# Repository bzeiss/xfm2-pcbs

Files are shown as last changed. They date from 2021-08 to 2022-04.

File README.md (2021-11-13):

# PCB(s) for the XFM2/XVA1 Project

This site contains some stuff I have built for the excellent FPGA XFM2/XVA FPGA DIY synths by futur3soundz/René Ceballos. You can find them here: https://www.futur3soundz.com.

I tinker with electronics, release stuff when I feel like it and I make it public when it's maybe not perfect. I'm not an electronics expert, so I may not always know what I'm doing. I learn the necessary electronics as I use it. Use at your own risk.

Feedback is always very welcome 😄 Feel free to ask question in the [discussions](https://github.com/bzeiss/xfm2-pcbs/discussions).

***

The main content of this site (descriptions, documentations) can be found **[in the Wiki](https://github.com/bzeiss/xfm2-pcbs/wiki)**.

Entrance (https://github.com/bzeiss/xfm2-pcbs/wiki)

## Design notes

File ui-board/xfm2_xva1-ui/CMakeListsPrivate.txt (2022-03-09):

# !!! WARNING !!! AUTO-GENERATED FILE, PLEASE DO NOT MODIFY IT AND USE
# https://docs.platformio.org/page/projectconf/section_env_build.html#build-flags
#
# If you need to override existing CMake configuration or add extra,
# please create `CMakeListsUser.txt` in the root of project.
# The `CMakeListsUser.txt` will not be overwritten by PlatformIO.

set(CMAKE_CONFIGURATION_TYPES "megaatmega2560" CACHE STRING "Build Types reflect PlatformIO Environments" FORCE)

# Convert "Home Directory" that may contain unescaped backslashes on Windows
file(TO_CMAKE_PATH $ENV{HOMEDRIVE}$ENV{HOMEPATH} ENV_HOME_PATH)

SET(CMAKE_C_COMPILER "${ENV_HOME_PATH}/.platformio/packages/toolchain-atmelavr/bin/avr-gcc.exe")
SET(CMAKE_CXX_COMPILER "${ENV_HOME_PATH}/.platformio/packages/toolchain-atmelavr/bin/avr-g++.exe")
SET(CMAKE_CXX_FLAGS "-fno-exceptions -fno-threadsafe-statics -fpermissive -std=gnu++11 -Wno-unknown-pragmas -Os -Wall -ffunction-sections -fdata-sections -flto -mmcu=atmega2560")
SET(CMAKE_C_FLAGS "-std=gnu11 -fno-fat-lto-objects -Wno-unknown-pragmas -Os -Wall -ffunction-sections -fdata-sections -flto -mmcu=atmega2560")

SET(CMAKE_C_STANDARD 11)
set(CMAKE_CXX_STANDARD 11)

if (CMAKE_BUILD_TYPE MATCHES "megaatmega2560")
    add_definitions(-DPLATFORMIO=50205)
    add_definitions(-DARDUINO_AVR_MEGA2560)
    add_definitions(-DF_CPU=16000000L)
    add_definitions(-DARDUINO_ARCH_AVR)
    add_definitions(-DARDUINO=10808)
    add_definitions(-D__AVR_ATmega2560__)

    include_directories("${CMAKE_CURRENT_LIST_DIR}/include")
    include_directories("${CMAKE_CURRENT_LIST_DIR}/src")
    include_directories("${CMAKE_CURRENT_LIST_DIR}/.pio/libdeps/megaatmega2560/Adafruit MCP23017 Arduino Library/src")
    include_directories("${CMAKE_CURRENT_LIST_DIR}/.pio/libdeps/megaatmega2560/Adafruit BusIO")
    include_directories("${CMAKE_CURRENT_LIST_DIR}/.pio/libdeps/megaatmega2560/SoftwareSerial")
    include_directories("${CMAKE_CURRENT_LIST_DIR}/.pio/libdeps/megaatmega2560/U8g2/src")
    include_directories("${ENV_HOME_PATH}/.platformio/packages/framework-arduino-avr/libraries/Wire/src")
    include_directories("${ENV_HOME_PATH}/.platformio/packages/framework-arduino-avr/libraries/SPI/src")
    include_directories("${ENV_HOME_PATH}/.platformio/packages/framework-arduino-avr/cores/arduino")
    include_directories("${ENV_HOME_PATH}/.platformio/packages/framework-arduino-avr/variants/mega")
    include_directories("${CMAKE_CURRENT_LIST_DIR}/.pio/libdeps/megaatmega2560/Adafruit MCP23017 Arduino Library@1.3.0")
    include_directories("${ENV_HOME_PATH}/.platformio/packages/framework-arduino-avr/libraries/EEPROM/src")
    include_directories("${ENV_HOME_PATH}/.platformio/packages/framework-arduino-avr/libraries/HID/src")
    include_directories("${ENV_HOME_PATH}/.platformio/packages/framework-arduino-avr/libraries/SoftwareSerial/src")
    include_directories("${ENV_HOME_PATH}/.platformio/packages/toolchain-atmelavr/lib/gcc/avr/7.3.0/include")
    include_directories("${ENV_HOME_PATH}/.platformio/packages/toolchain-atmelavr/lib/gcc/avr/7.3.0/include-fixed")
    include_directories("${ENV_HOME_PATH}/.platformio/packages/toolchain-atmelavr/avr/include")

    FILE(GLOB_RECURSE EXTRA_LIB_SOURCES
        ${CMAKE_CURRENT_LIST_DIR}/.pio/libdeps/megaatmega2560/*.*
    )
endif()

FILE(GLOB_RECURSE SRC_LIST
    ${CMAKE_CURRENT_LIST_DIR}/src/*.*
    ${CMAKE_CURRENT_LIST_DIR}/lib/*.*
    ${CMAKE_CURRENT_LIST_DIR}/test/*.*
)

list(APPEND SRC_LIST ${EXTRA_LIB_SOURCES})

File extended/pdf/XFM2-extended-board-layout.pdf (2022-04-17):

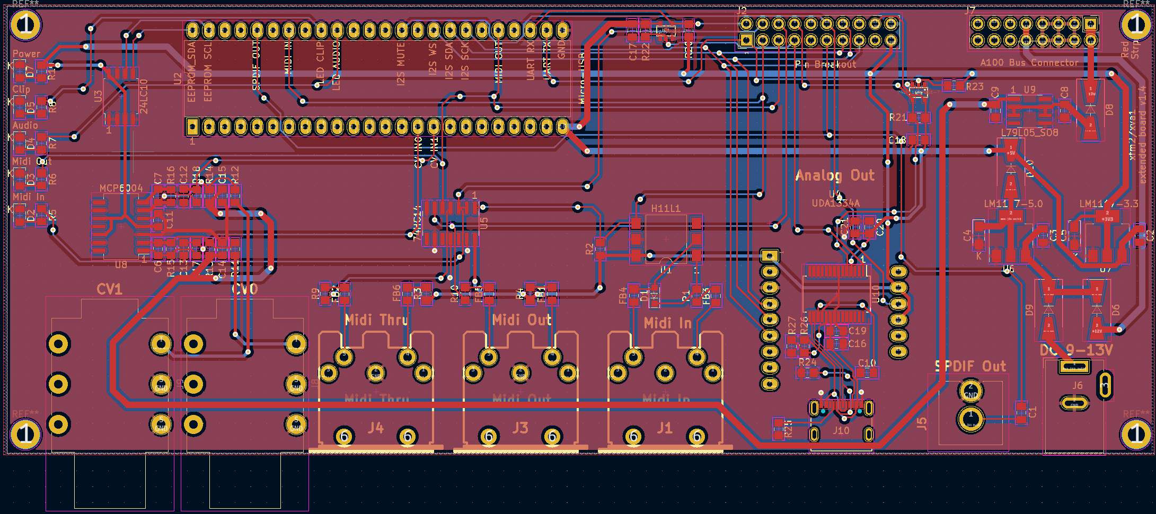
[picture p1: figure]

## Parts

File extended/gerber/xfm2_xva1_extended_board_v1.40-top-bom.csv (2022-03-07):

Comment | Designator | Footprint | LCSC Part Number
10nF | C1,C19,C20 | Capacitor_SMD:C_0805_2012Metric_Pad1.18x1.45mm_HandSolder | C1710
1uF | C10 | Capacitor_SMD:C_0805_2012Metric_Pad1.18x1.45mm_HandSolder | C28323
100pF | C12,C13 | Capacitor_SMD:C_0805_2012Metric_Pad1.18x1.45mm_HandSolder | C1790
0.1uF | C16,C21 | Capacitor_SMD:C_0805_2012Metric_Pad1.18x1.45mm_HandSolder | C49678
10uF | C2,C3 | Capacitor_SMD:C_0805_2012Metric_Pad1.18x1.45mm_HandSolder | C15850
10uF | C4,C5 | Capacitor_Tantalum_SMD:CP_EIA-3216-18_Kemet-A_Pad1.58x1.35mm_HandSolder | C7171
330p-560p | C6,C7 | Capacitor_SMD:C_0805_2012Metric_Pad1.18x1.45mm_HandSolder | C51207
330nF | C8 | Capacitor_SMD:C_0805_2012Metric_Pad1.18x1.45mm_HandSolder | C1740
100nF | C9,C11,C14,C15,C17,C18 | Capacitor_SMD:C_0805_2012Metric_Pad1.18x1.45mm_HandSolder | C49678
1N4148 | D1 | Diode_SMD:D_SOD-323_HandSoldering | C2128
LED_MIDI_IN | D2 | LED_SMD:LED_0805_2012Metric_Pad1.15x1.40mm_HandSolder | C2293
LED_MIDI_OUT | D3 | LED_SMD:LED_0805_2012Metric_Pad1.15x1.40mm_HandSolder | C2296
LED_CLIP | D5 | LED_SMD:LED_0805_2012Metric_Pad1.15x1.40mm_HandSolder | C434431
1N5819/SS14 | D6,D8,D9,D10 | Diode_SMD:D_SMA-SMB_Universal_Handsoldering | C2480
LED_POWER | D7 | LED_SMD:LED_0805_2012Metric_Pad1.15x1.40mm_HandSolder | C434432
Ferrite_Bead | FB1,FB2,FB3,FB4,FB5,FB6 | Capacitor_SMD:C_0805_2012Metric_Pad1.18x1.45mm_HandSolder | C76810
74LVC1G07QSE-7 | IC1,IC2 | greatscott:SOT25 | C507244
220 | R1 | Resistor_SMD:R_0805_2012Metric_Pad1.20x1.40mm_HandSolder | C17557
100k | R11,R12,R13,R14 | Resistor_SMD:R_0805_2012Metric_Pad1.20x1.40mm_HandSolder | C149504
33k | R15,R16 | Resistor_SMD:R_0805_2012Metric_Pad1.20x1.40mm_HandSolder | C17633
100 | R17,R18 | Resistor_SMD:R_0805_2012Metric_Pad1.20x1.40mm_HandSolder | C17408
470 | R2 | Resistor_SMD:R_0805_2012Metric_Pad1.20x1.40mm_HandSolder | C17710
10k | R20,R21,R22,R23,R27 | Resistor_SMD:R_0805_2012Metric_Pad1.20x1.40mm_HandSolder | C17414
5.1k | R24,R25 | Resistor_SMD:R_0805_2012Metric_Pad1.20x1.40mm_HandSolder | C27834
4.7k | R26 | Resistor_SMD:R_0805_2012Metric_Pad1.20x1.40mm_HandSolder | C17673
33 | R3,R4 | Resistor_SMD:R_0805_2012Metric_Pad1.20x1.40mm_HandSolder | C17634
2k | R5,R6,R7,R8,R19 | Resistor_SMD:R_0805_2012Metric_Pad1.20x1.40mm_HandSolder | C17604
10 | R9,R10 | Resistor_SMD:R_0805_2012Metric_Pad1.20x1.40mm_HandSolder | C17415
H11L1 | U1 | Package_DIP:SMDIP-6_W9.53mm_Clearance8mm | C20082
CY7C65213-28PVXI | U10 | Package_SO:SSOP-28_5.3x10.2mm_P0.65mm | C134181
24LC10 | U3 | Package_SO:SOIC-8_5.275x5.275mm_P1.27mm | C1348777
74HC14 | U5 | Package_SO:SO-14_3.9x8.65mm_P1.27mm | C6820
LM1117-5.0 | U6 | Package_TO_SOT_SMD:SOT-223-3_TabPin2 | C126028
LM1117-3.3 | U7 | Package_TO_SOT_SMD:SOT-223-3_TabPin2 | C126027
L79L05_SO8 | U9 | Package_SO:SOIC-8_3.9x4.9mm_P1.27mm | C2802525

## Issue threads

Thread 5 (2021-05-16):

Add external power supply

bzeiss, 2021-05-16:
The board is currently powered via USB. A power connector compatible with Eurorack would be nice.

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

Details: http://www.doepfer.de/a100_man/a100t_e.htm

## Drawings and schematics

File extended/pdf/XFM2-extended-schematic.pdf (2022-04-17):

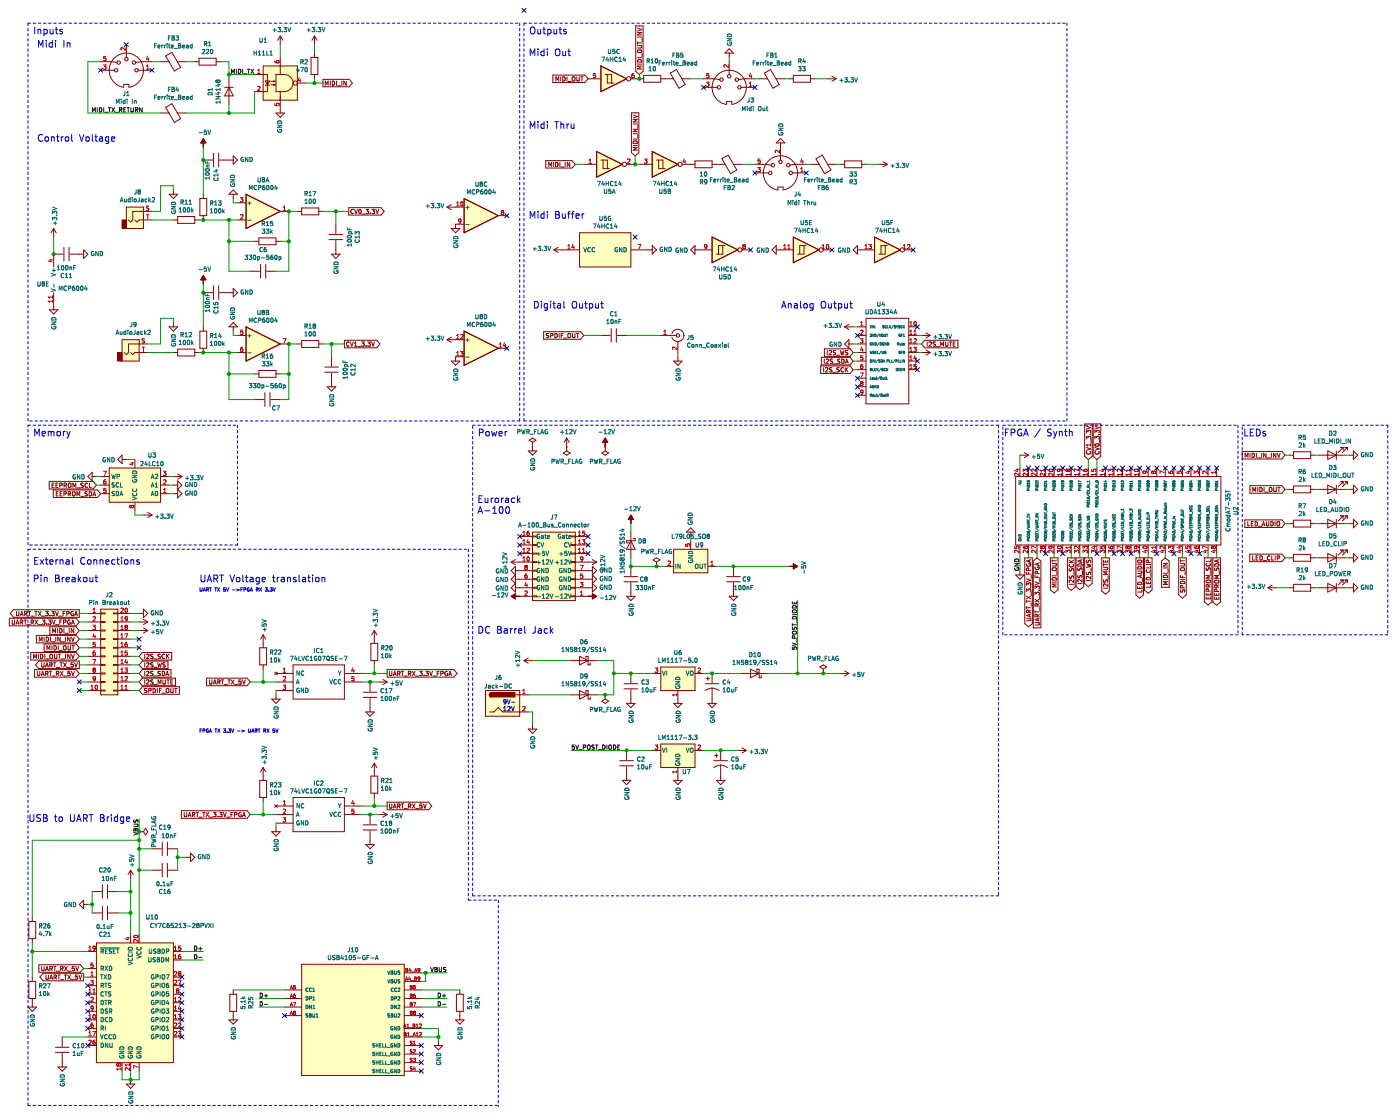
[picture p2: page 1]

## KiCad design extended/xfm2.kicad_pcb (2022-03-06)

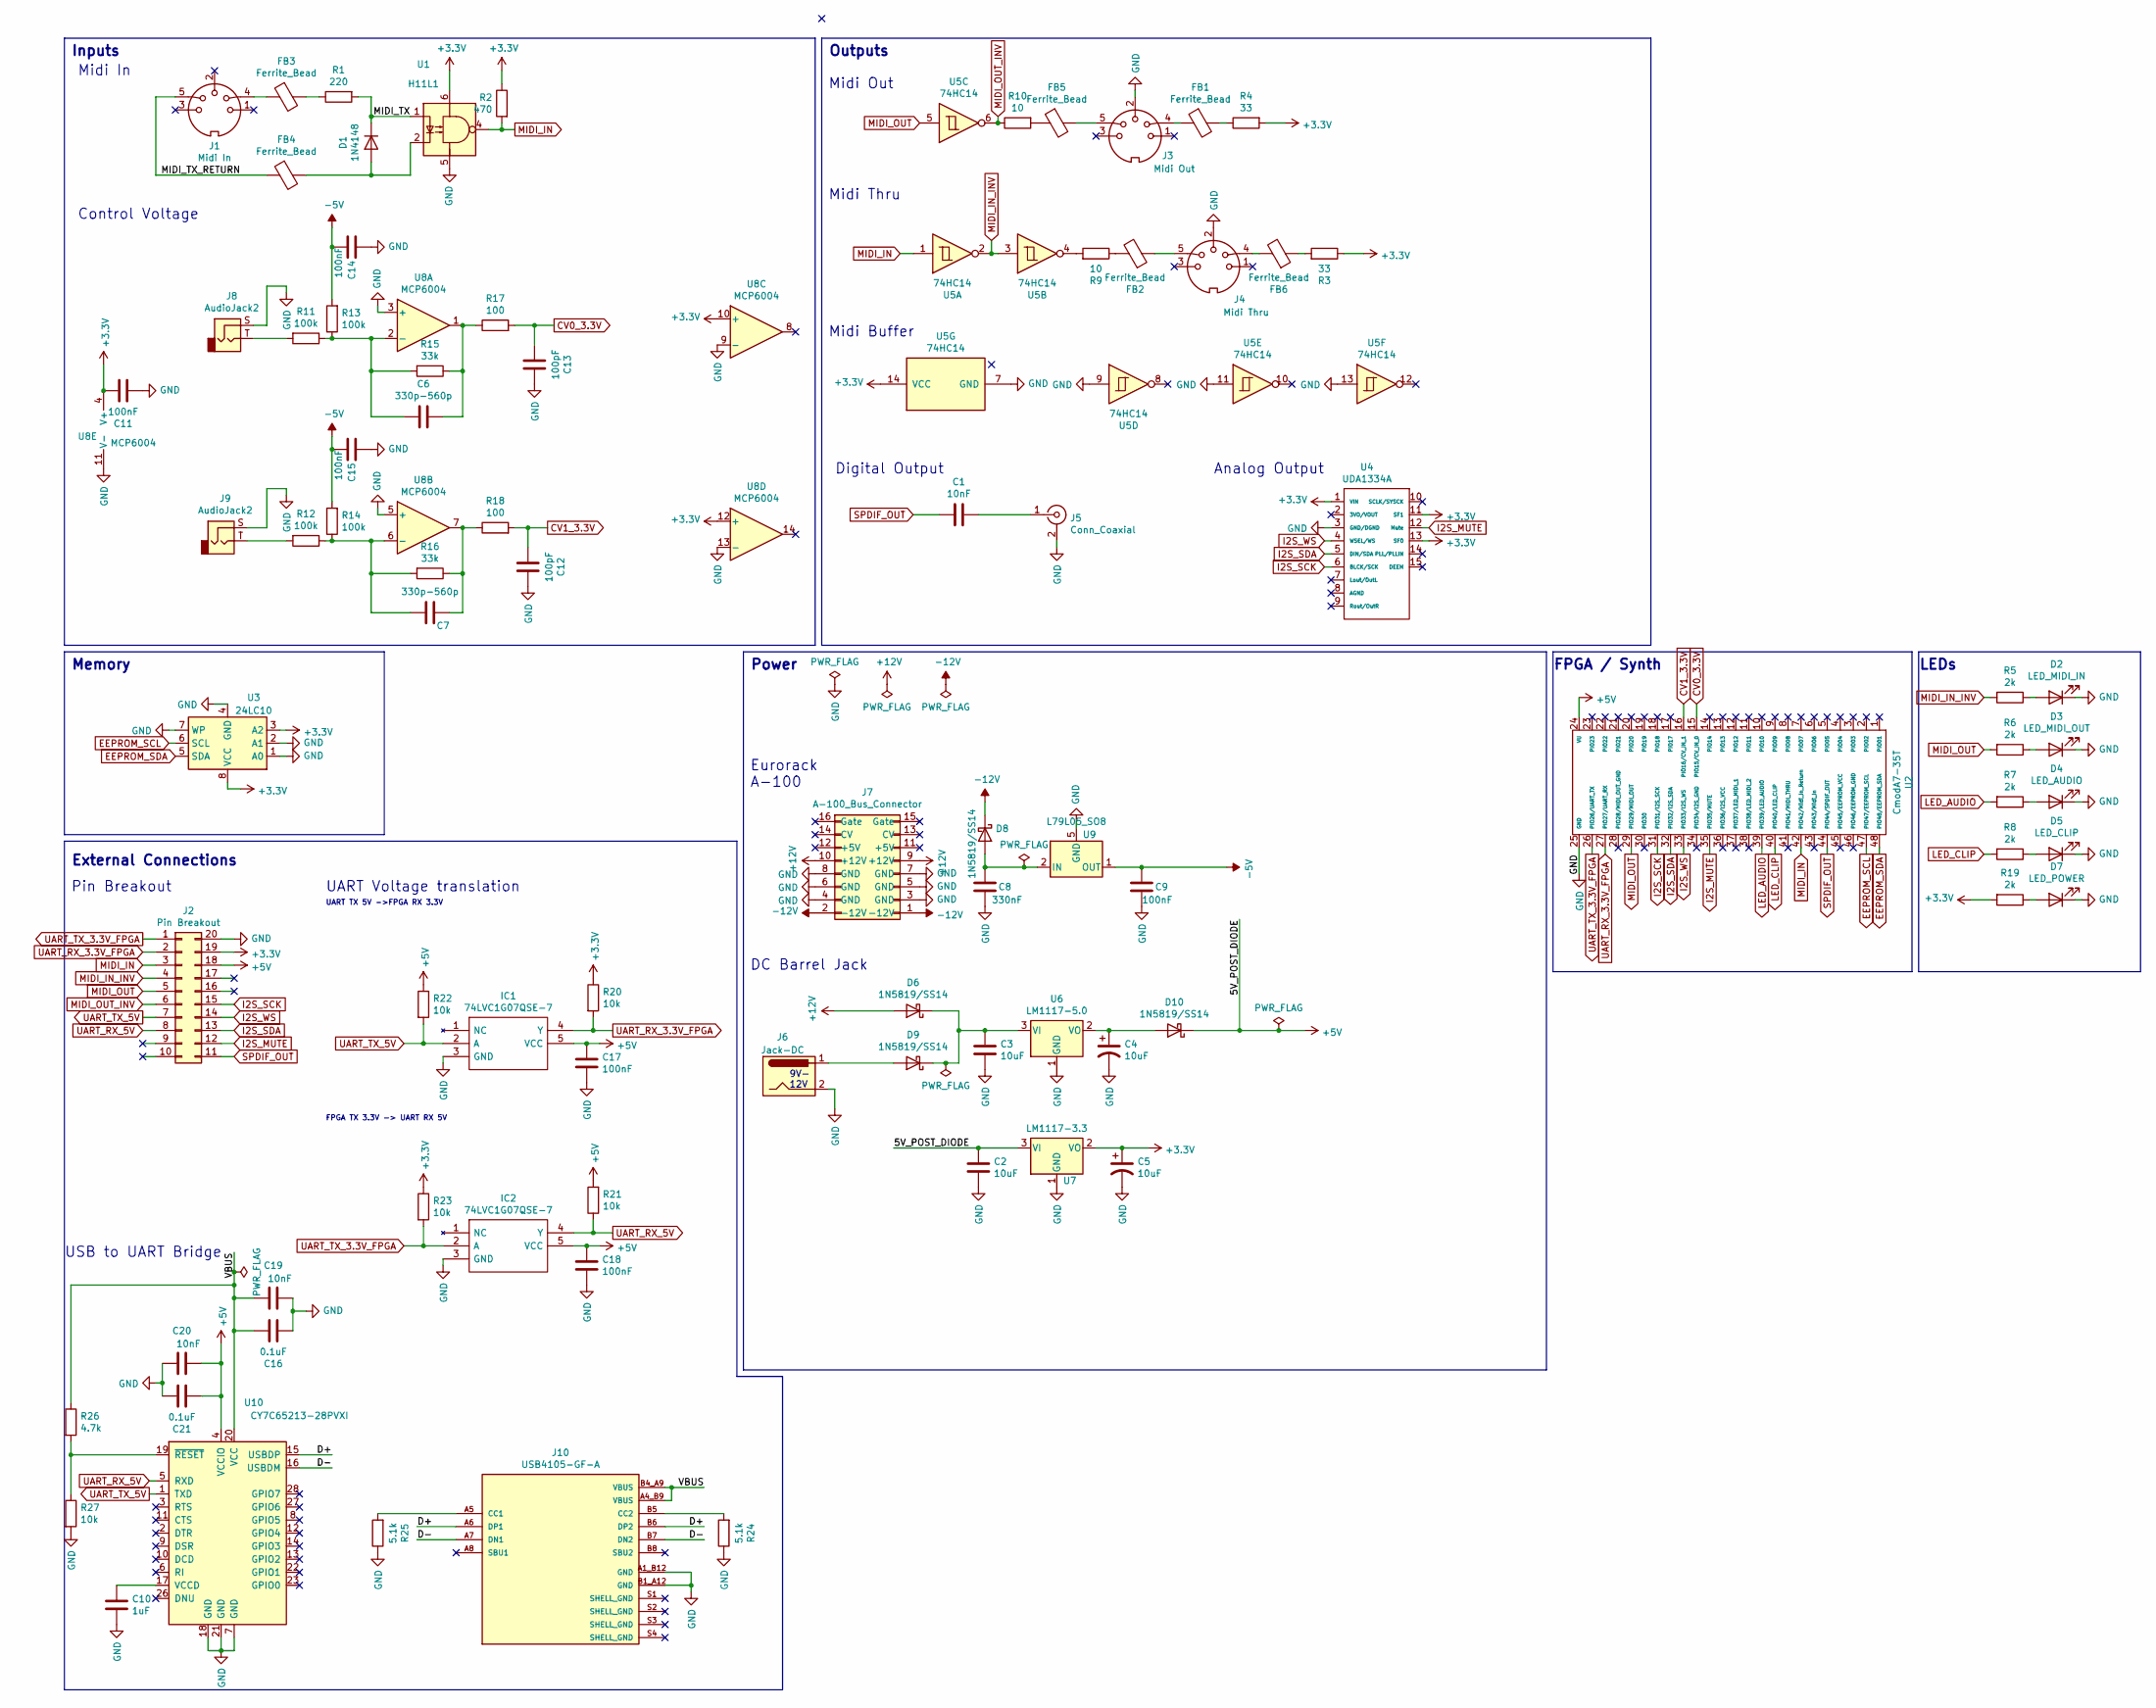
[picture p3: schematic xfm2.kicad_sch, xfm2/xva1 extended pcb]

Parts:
C1, C19, C20: 10nF; C_0805_2012Metric_Pad1.18x1.45mm_HandSolder; LCSC C1710
C2, C3: 10uF; C_0805_2012Metric_Pad1.18x1.45mm_HandSolder; LCSC C15850
C4, C5: 10uF; CP_EIA-3216-18_Kemet-A_Pad1.58x1.35mm_HandSolder; LCSC C7171
C6, C7: 330p-560p; C_0805_2012Metric_Pad1.18x1.45mm_HandSolder; LCSC C51207
C8: 330nF; C_0805_2012Metric_Pad1.18x1.45mm_HandSolder; LCSC C1740
C9, C11, C14, C15, C17, C18: 100nF; C_0805_2012Metric_Pad1.18x1.45mm_HandSolder; LCSC C49678
C10: 1uF; C_0805_2012Metric_Pad1.18x1.45mm_HandSolder; LCSC C28323
C12, C13: 100pF; C_0805_2012Metric_Pad1.18x1.45mm_HandSolder; LCSC C1790
C16, C21: 0.1uF; C_0805_2012Metric_Pad1.18x1.45mm_HandSolder; LCSC C49678
D1: 1N4148; D_SOD-323_HandSoldering; LCSC C2128
D2: LED_MIDI_IN; LED_0805_2012Metric_Pad1.15x1.40mm_HandSolder; LCSC C2293
D3: LED_MIDI_OUT; LED_0805_2012Metric_Pad1.15x1.40mm_HandSolder; LCSC C2296
D4: LED_AUDIO; LED_0805_2012Metric_Pad1.15x1.40mm_HandSolder
D5: LED_CLIP; LED_0805_2012Metric_Pad1.15x1.40mm_HandSolder; LCSC C434431
D6, D8, D9, D10: 1N5819/SS14; D_SMA-SMB_Universal_Handsoldering; LCSC C2480
D7: LED_POWER; LED_0805_2012Metric_Pad1.15x1.40mm_HandSolder; LCSC C2297
FB1, FB2, FB3, FB4, FB5, FB6: Ferrite_Bead; C_0805_2012Metric_Pad1.18x1.45mm_HandSolder; LCSC C76810
IC1, IC2: 74LVC1G07QSE-7; SOT25; Mouser Part Number 621-74LVC1G07QSE-7
J1: Midi In; din-5
J2: Pin Breakout; PinHeader_2x10_P2.54mm_Vertical
J3: Midi Out; din-5
J4: Midi Thru; din-5
J5: Conn_Coaxial; KLPX0848A2Y
J6: Jack-DC; BarrelJack_Wuerth_6941xx301002
J7: A-100_Bus_Connector; PinHeader_2x08_P2.54mm_Vertical
J8, J9: AudioJack2; Jack_6.35mm_Neutrik_NMJ6HFD2_Horizontal-ST-only
J10: USB4105-GF-A; GCT_USB4105-GF-A; PARTREV A3
R1: 220; R_0805_2012Metric_Pad1.20x1.40mm_HandSolder; LCSC C17557
R2: 470; R_0805_2012Metric_Pad1.20x1.40mm_HandSolder; LCSC C17710
R3, R4: 33; R_0805_2012Metric_Pad1.20x1.40mm_HandSolder; LCSC C17634
R5, R6, R7, R8, R19: 2k; R_0805_2012Metric_Pad1.20x1.40mm_HandSolder; LCSC C17604
R9, R10: 10; R_0805_2012Metric_Pad1.20x1.40mm_HandSolder; LCSC C17415
R11, R12, R13, R14: 100k; R_0805_2012Metric_Pad1.20x1.40mm_HandSolder; LCSC C149504
R15, R16: 33k; R_0805_2012Metric_Pad1.20x1.40mm_HandSolder; LCSC C17633
R17, R18: 100; R_0805_2012Metric_Pad1.20x1.40mm_HandSolder; LCSC C17408
R20, R21, R22, R23, R27: 10k; R_0805_2012Metric_Pad1.20x1.40mm_HandSolder; LCSC C17414
R24, R25: 5.1k; R_0805_2012Metric_Pad1.20x1.40mm_HandSolder; LCSC C27834
R26: 4.7k; R_0805_2012Metric_Pad1.20x1.40mm_HandSolder; LCSC C17673
U1: H11L1; SMDIP-6_W9.53mm_Clearance8mm; LCSC C20082
U2: CmodA7-35T; DIP-48_W15.24mm_LongPads
U3: 24LC10; SOIC-8_5.275x5.275mm_P1.27mm; LCSC C1348777
U4: UDA1334A; Adafruit_UDA1334A_Breakout
U5: 74HC14; SO-14_3.9x8.65mm_P1.27mm; LCSC C6820
U6: LM1117-5.0; SOT-223-3_TabPin2; LCSC C126028
U7: LM1117-3.3; SOT-223-3_TabPin2; LCSC C126027
U8: MCP6004; SO-14_5.3x10.2mm_P1.27mm; LCSC C7378
U9: L79L05_SO8; SOIC-8_3.9x4.9mm_P1.27mm; LCSC C2802525
U10: CY7C65213-28PVXI; SSOP-28_5.3x10.2mm_P0.65mm; LCSC C134181

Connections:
+3V3: C5.1, C11.1, J2.19, R2.1, R3.1, R4.2, R19.2, R20.1, R23.1, U1.6, U3.3 (A2), U3.8 (VCC), U4.1 (VIN), U4.11 (SF1), U4.13 (SF0), U5.14 (VCC), U7.2 (VO), U8.4 (V+), U8.10 (+), U8.12 (+)
+5V: C2.1, C17.1, C18.1, C20.2, C21.2, D10.1 (K), IC1.5 (VCC), IC2.5 (VCC), J2.18, R21.2, R22.1, U2.24 (VU), U7.3 (VI), U10.4 (VCCIO)
+12V: D6.2 (A), J7.9 (+12V), J7.10 (+12V)
-5V: C9.1, C14.2, C15.2, R13.2, R14.2, U9.1 (OUT)
-12V: D8.1 (K), J7.1 (-12V), J7.2 (-12V)
/D+: J10.A6 (DP1), J10.B6 (DP2), U10.15 (USBDP)
/D-: J10.A7 (DN1), J10.B7 (DN2), U10.16 (USBDM)
/MIDI_TX: D1.1 (K), R1.2, U1.1
/MIDI_TX_RETURN: FB4.1, J1.5
/VBUS: C16.1, C19.1, J10.A4_B9 (VBUS), J10.B4_A9 (VBUS), R26.1, U10.20 (VCC)
CV0_3.3V: C13.2, R17.2, U2.15 (PIO15/CV_IN_0)
CV1_3.3V: C12.2, R18.2, U2.16 (PIO16/CV_IN_1)
EEPROM_SCL: U2.47 (PIO47/EEPROM_SCL), U3.6 (SCL)
EEPROM_SDA: U2.48 (PIO48/EEPROM_SDA), U3.5 (SDA)
GND: C2.2, C3.2, C4.2, C5.2, C8.2, C9.2, C10.2, C11.2, C12.1, C13.1, C14.1, C15.1, C16.2, C17.2, C18.2, C19.2, C20.1, C21.1, D2.1 (K), D3.1 (K), D4.1 (K), D5.1 (K), D7.1 (K), IC1.3 (GND), IC2.3 (GND), J2.20, J3.2, J4.2, J5.2 (Ext), J6.2, J7.3 (GND), J7.4 (GND), J7.5 (GND), J7.6 (GND), J7.7 (GND), J7.8 (GND), J8.S, J9.S, J10.A1_B12 (GND), J10.B1_A12 (GND), R24.1, R25.1, R27.2, U1.5, U2.25 (GND), U3.1 (A0), U3.2 (A1), U3.4 (GND), U3.7 (WP), U4.3 (GND/DGND), U5.7 (GND), U5.9, U5.11, U5.13, U6.1 (GND), U7.1 (GND), U8.3 (+), U8.5 (+), U8.9 (-), U8.11 (V-), U8.13 (-), U9.5 (GND), U10.7 (GND), U10.18 (GND), U10.21 (GND)
I2S_MUTE: J2.12, U2.35 (PIO35/MUTE), U4.12 (Mute)
I2S_SCK: J2.15, U2.31 (PIO31/I2S_SCK), U4.6 (BLCK/SCK)
I2S_SDA: J2.13, U2.32 (PIO32/I2S_SDA), U4.5 (DIN/SDA)
I2S_WS: J2.14, U2.33 (PIO33/I2S_WS), U4.4 (WSEL/WS)
LED_AUDIO: R7.2, U2.39 (PIO39/LED_AUDIO)
LED_CLIP: R8.2, U2.40 (PIO40/LED_CLIP)
MIDI_IN: J2.3, R2.2, U1.4, U2.42 (PIO42/Midi_In_Return), U5.1
MIDI_IN_INV: J2.4, R5.2, U5.2, U5.3
MIDI_OUT: J2.5, R6.2, U2.29 (PIO29/MIDI_OUT), U5.5
MIDI_OUT_INV: J2.6, R10.1, U5.6
unnamed: C1.1, J5.1 (In)
unnamed: C3.1, D6.1 (K), D9.1 (K), U6.3 (VI)
unnamed: C4.1, D10.2 (A), U6.2 (VO)
unnamed: C6.1, R15.1, R17.1, U8.1
unnamed: C6.2, R11.1, R13.1, R15.2, U8.2 (-)
unnamed: C7.1, R16.1, R18.1, U8.7
unnamed: C7.2, R12.1, R14.1, R16.2, U8.6 (-)
unnamed: C8.1, D8.2 (A), U9.2 (IN), U9.3 (IN), U9.6 (IN), U9.7 (IN)
unnamed: C10.1, U10.17 (VCCD)
unnamed: D1.2 (A), FB4.2, U1.2
unnamed: D2.2 (A), R5.1
unnamed: D3.2 (A), R6.1
unnamed: D4.2 (A), R7.1
unnamed: D5.2 (A), R8.1
unnamed: D7.2 (A), R19.1
unnamed: D9.2 (A), J6.1
unnamed: FB1.1, J3.4
unnamed: FB1.2, R4.1
unnamed: FB2.1, J4.5
unnamed: FB2.2, R9.1
unnamed: FB3.1, J1.4
unnamed: FB3.2, R1.1
unnamed: FB5.1, R10.2
unnamed: FB5.2, J3.5
unnamed: FB6.1, R3.2
unnamed: FB6.2, J4.4
unnamed: J8.T, R11.2
unnamed: J9.T, R12.2
unnamed: J10.A5 (CC1), R25.2
unnamed: J10.B5 (CC2), R24.2
unnamed: R9.2, U5.4
unnamed: R26.2, R27.1, U10.19 (~RESET)
SPDIF_OUT: C1.2, J2.11, U2.44 (PIO44/SPDIF_OUT)
UART_RX_3.3V_FPGA: IC1.4 (Y), J2.2, R20.2, U2.27 (PIO27/UART_RX)
UART_RX_5V: IC2.4 (Y), J2.8, R21.1, U10.5 (RXD)
UART_TX_3.3V_FPGA: IC2.2 (A), J2.1, R23.2, U2.26 (PIO26/UART_TX)
UART_TX_5V: IC1.2 (A), J2.7, R22.2, U10.1 (TXD)

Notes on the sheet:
Inputs
FPGA / Synth
DC Barrel Jack
External Connections
Outputs
Eurorack A-100
UART TX 5V ->FPGA RX 3.3V
Midi Out
9V- 12V
Digital Output
Control Voltage
Midi Thru
Power
LEDs
Pin Breakout
Midi Buffer
USB to UART Bridge
Memory
FPGA TX 3.3V -> UART RX 5V
Midi In
Analog Output
UART Voltage translation

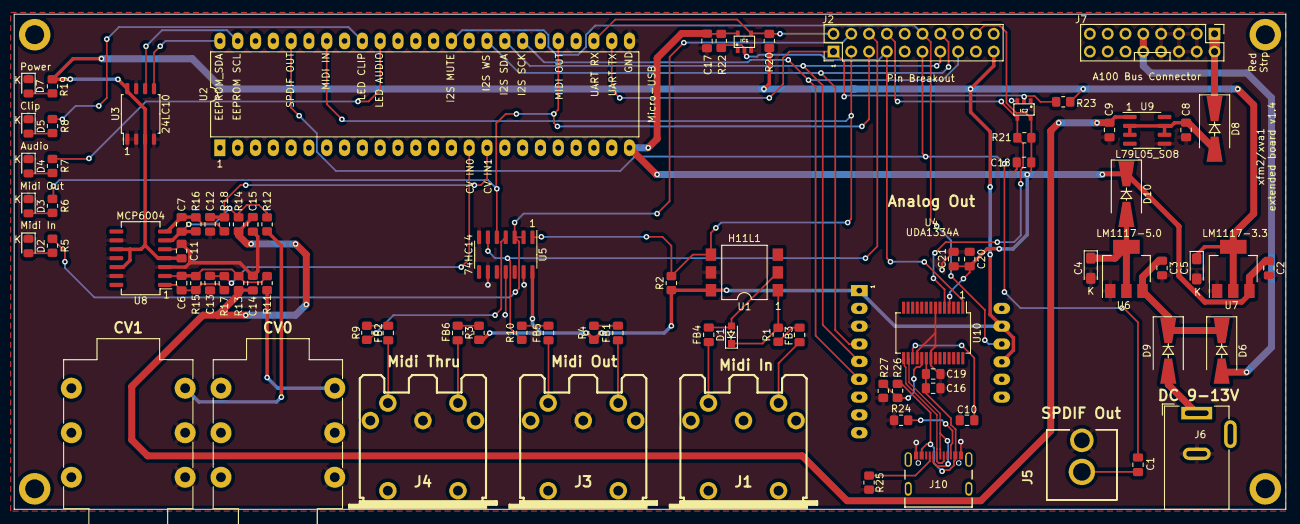
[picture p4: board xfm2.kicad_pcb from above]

Board: 2 copper layers, 181.4 x 70.6 mm, 86 parts (0 on the bottom side), 62 nets.

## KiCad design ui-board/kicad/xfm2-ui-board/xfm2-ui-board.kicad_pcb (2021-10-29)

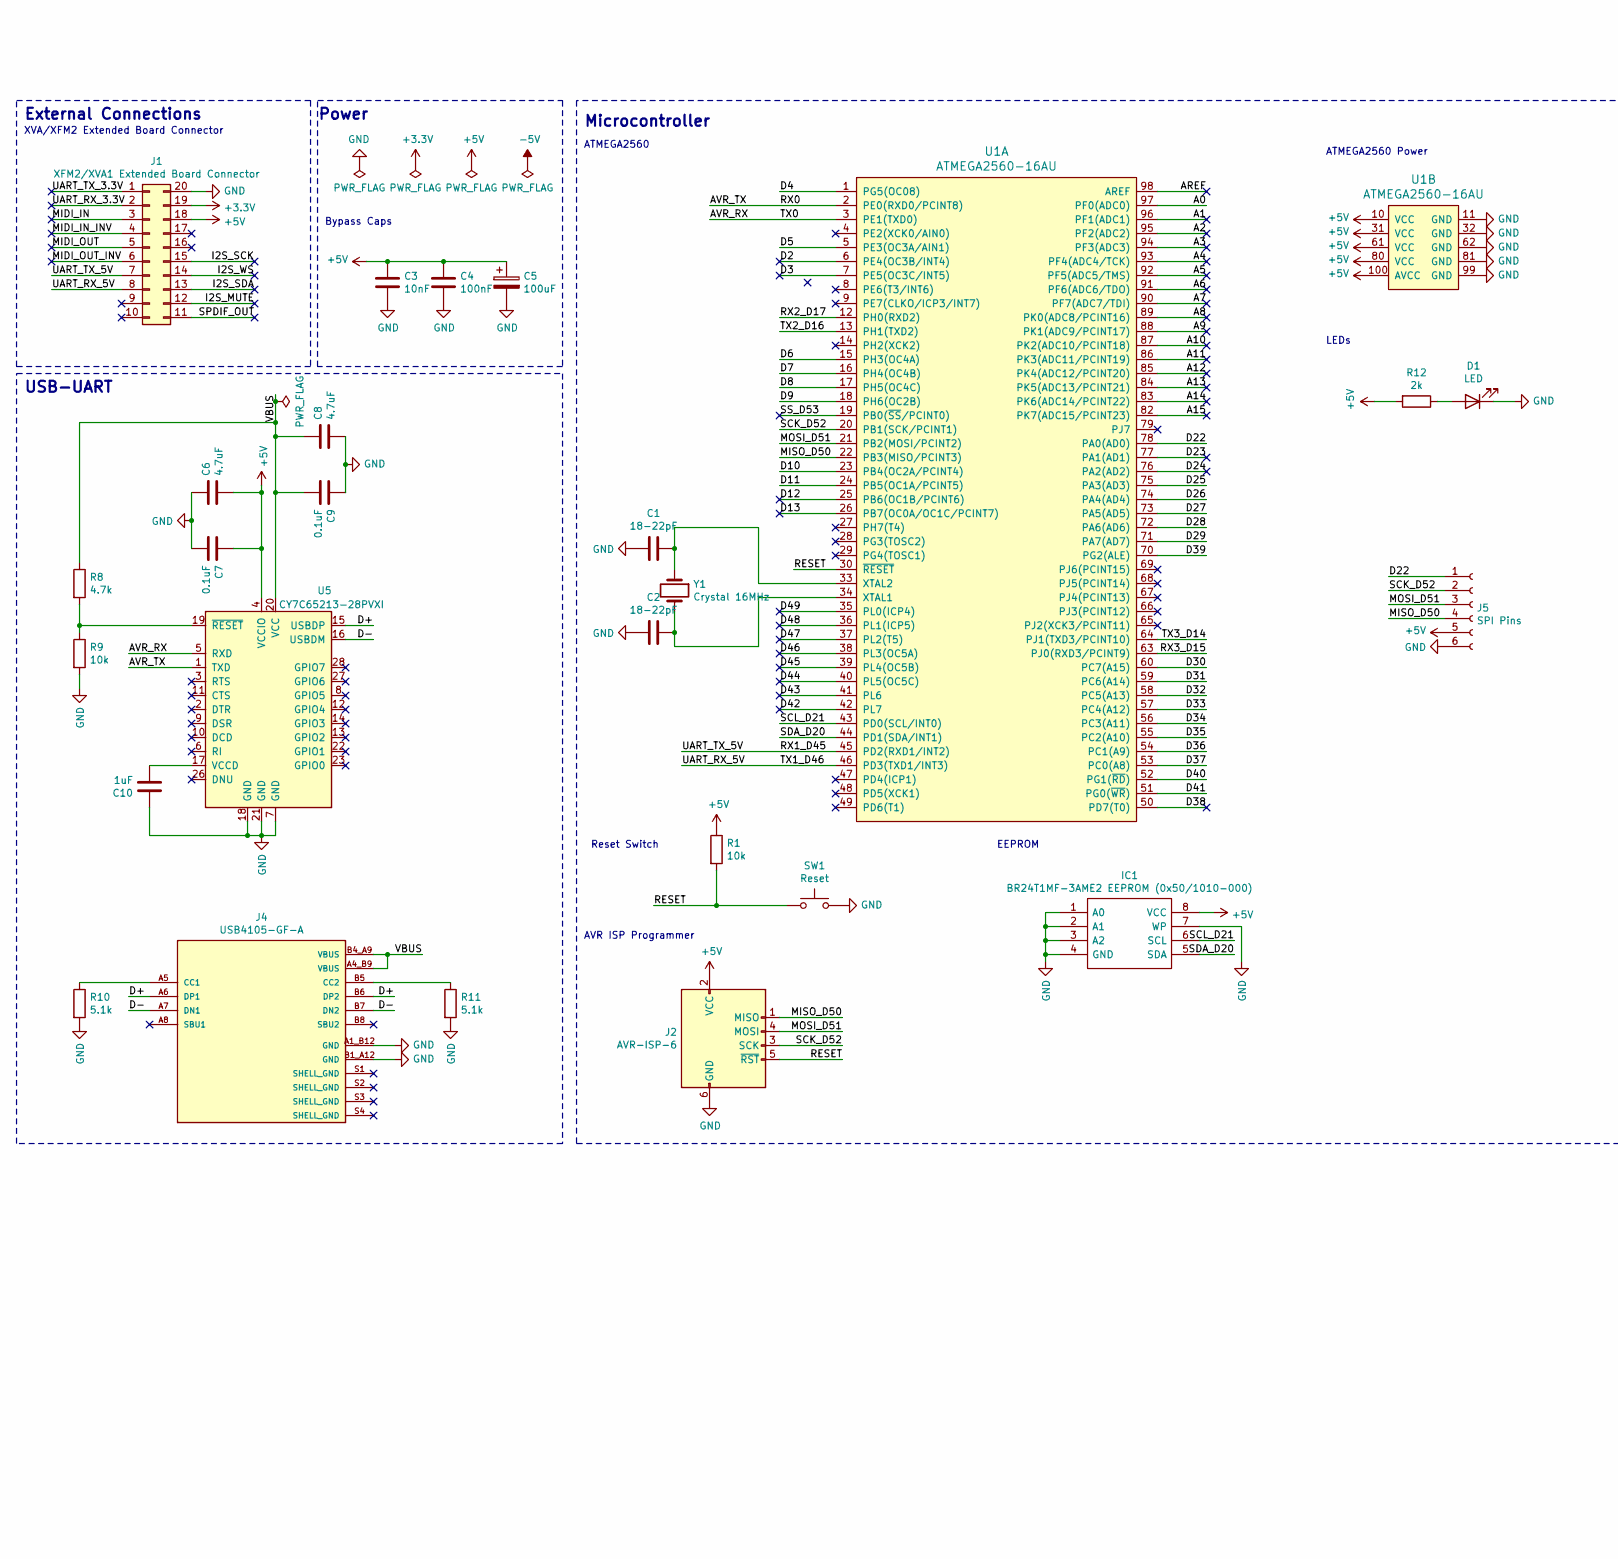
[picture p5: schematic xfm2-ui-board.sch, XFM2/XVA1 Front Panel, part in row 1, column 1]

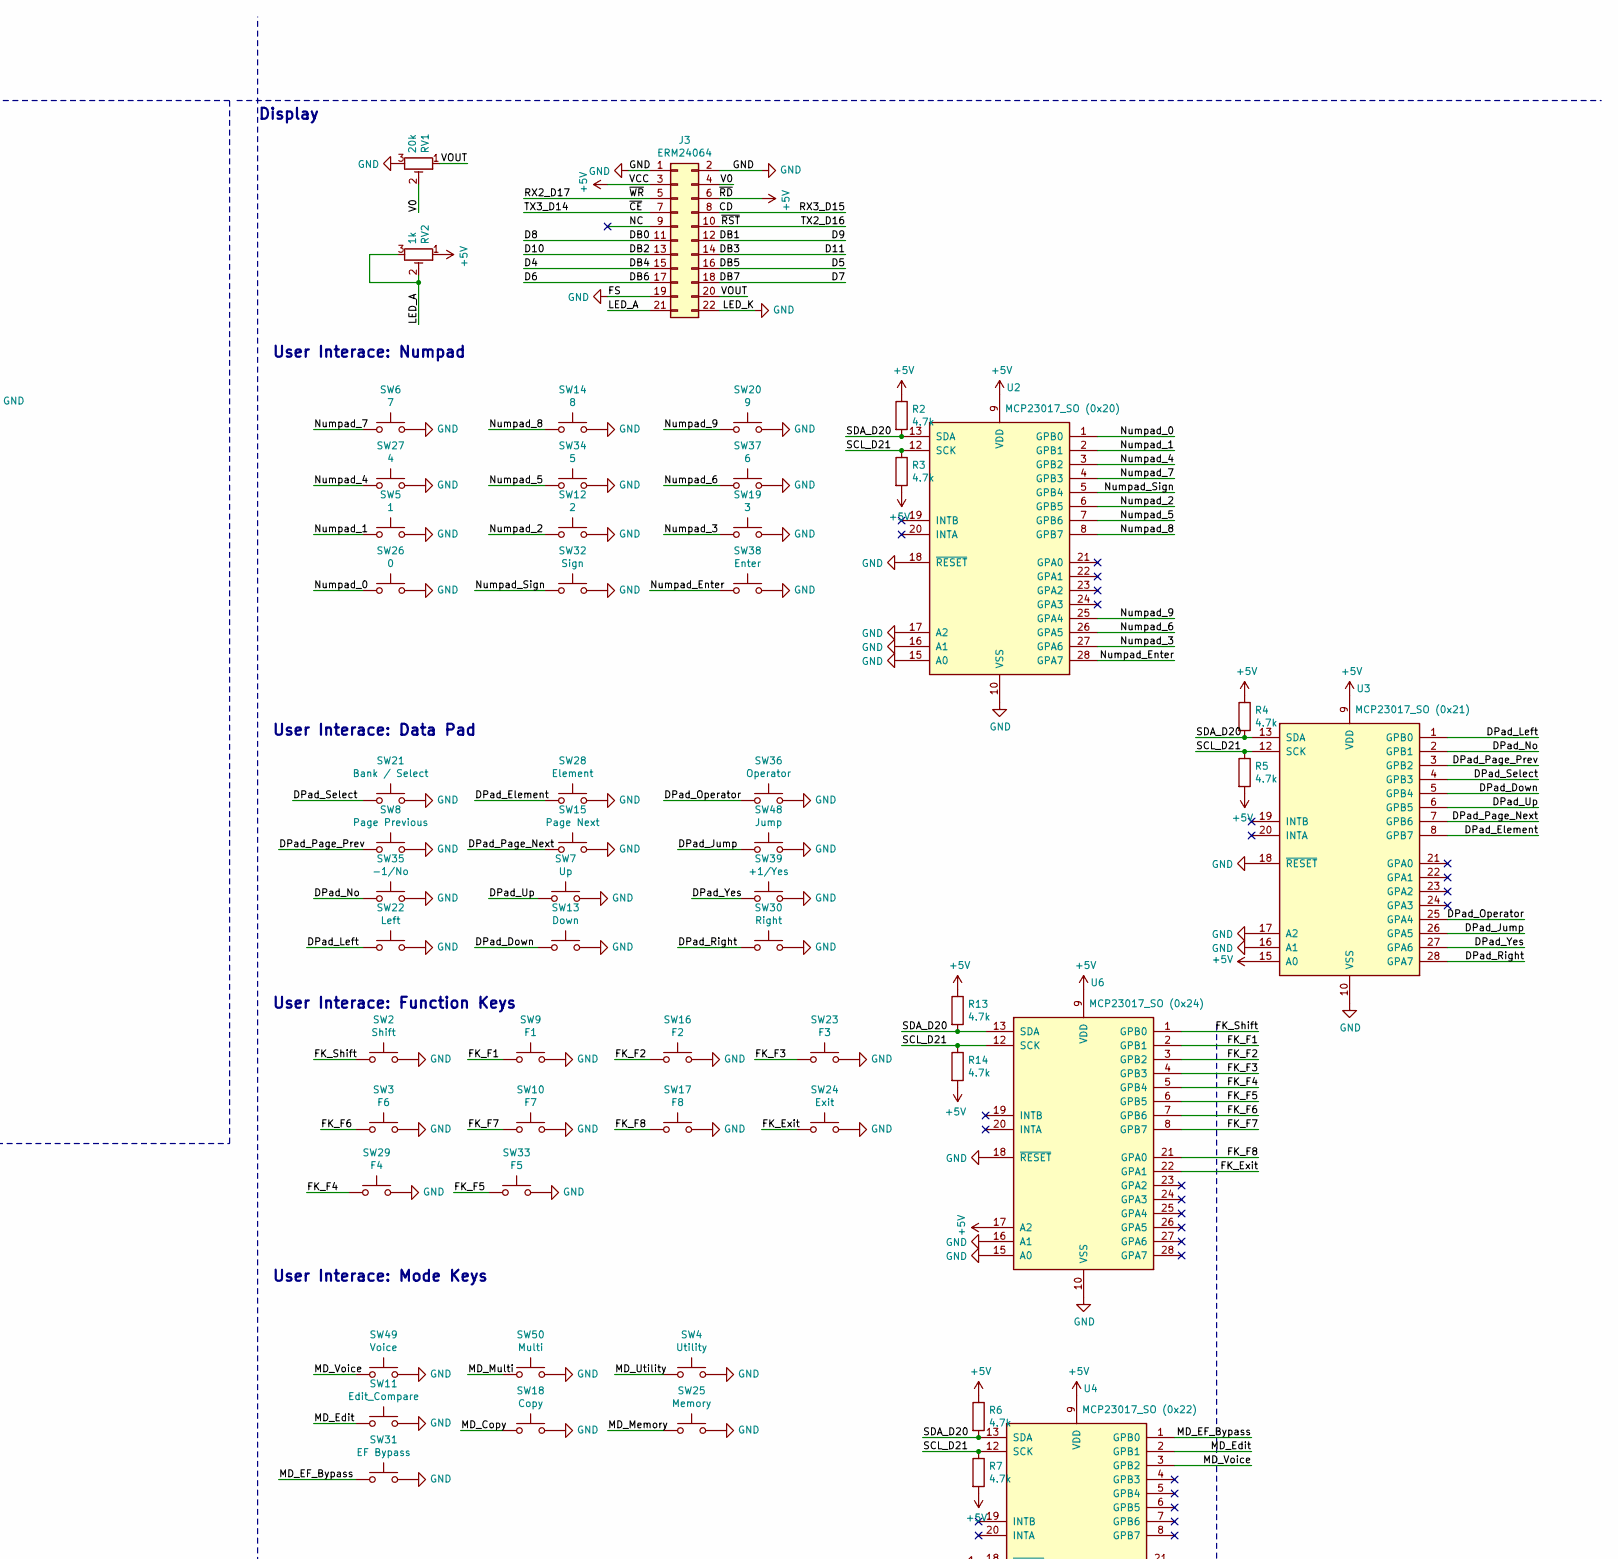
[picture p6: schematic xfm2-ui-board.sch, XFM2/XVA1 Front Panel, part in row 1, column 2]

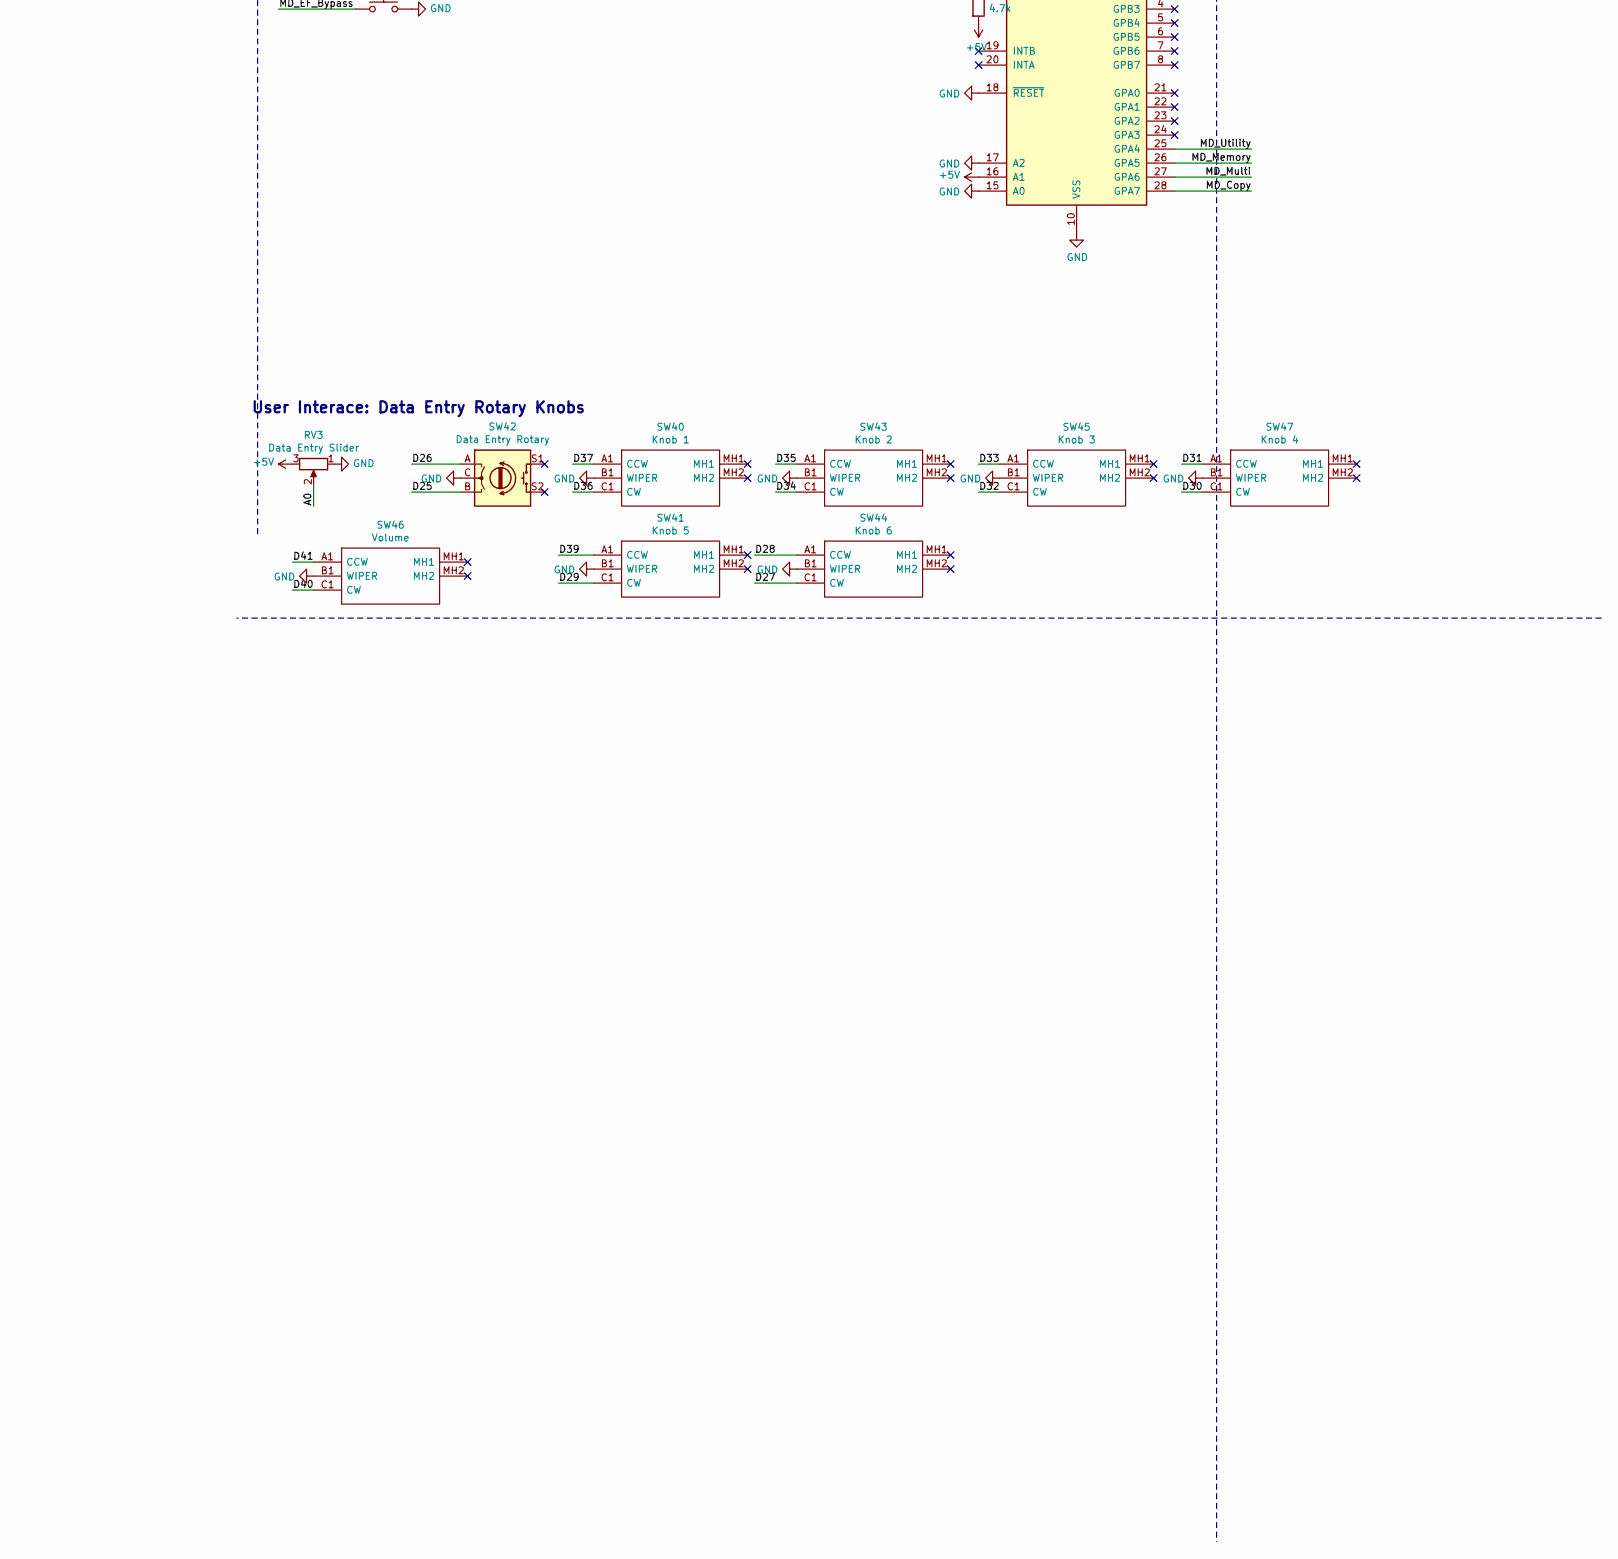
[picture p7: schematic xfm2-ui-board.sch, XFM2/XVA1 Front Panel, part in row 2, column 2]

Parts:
C1, C2: 18-22pF; C_0805_2012Metric_Pad1.18x1.45mm_HandSolder
C3: 10nF; C_0805_2012Metric_Pad1.18x1.45mm_HandSolder
C4: 100nF; C_0805_2012Metric_Pad1.18x1.45mm_HandSolder
C5: 100uF; CP_Elec_5x4.4
C6, C8: 4.7uF; C_0805_2012Metric_Pad1.18x1.45mm_HandSolder
C7, C9: 0.1uF; C_0805_2012Metric_Pad1.18x1.45mm_HandSolder
C10: 1uF; C_0805_2012Metric_Pad1.18x1.45mm_HandSolder
D1: LED; LED_0805_2012Metric_Pad1.15x1.40mm_HandSolder
IC1: BR24T1MF-3AME2 EEPROM (0x50/1010-000); SOIC127P620X171-8N; Mouser Part Number 755-BR24T1MF-3AME2
J1: XFM2/XVA1 Extended Board Connector; PinHeader_2x10_P2.54mm_Vertical
J2: AVR-ISP-6; PinHeader_1x06_P2.54mm_Vertical
J3: ERM24064; PinHeader_2x11_P2.54mm_Vertical
J4: USB4105-GF-A; GCT_USB4105-GF-A; PARTREV A3
J5: SPI Pins; PinHeader_1x06_P2.54mm_Vertical
R1, R9: 10k; R_0805_2012Metric_Pad1.20x1.40mm_HandSolder
R2, R3, R4, R5, R6, R7, R8, R13, R14: 4.7k; R_0805_2012Metric_Pad1.20x1.40mm_HandSolder
R10, R11: 5.1k; R_0805_2012Metric_Pad1.20x1.40mm_HandSolder
R12: 2k; R_0805_2012Metric_Pad1.20x1.40mm_HandSolder
RV1: 20k; Potentiometer_ACP_CA9-V10_Vertical
RV2: 1k; Potentiometer_ACP_CA9-V10_Vertical
RV3: Data Entry Slider; RS30111A9012
SW1: Reset; SW_PUSH_6mm
SW2: Shift; SW_PUSH_6mm
SW3: F6; SW_PUSH_6mm
SW4: Utility; SW_PUSH_6mm
SW5: 1; SW_PUSH_6mm
SW6: 7; SW_PUSH_6mm
SW7: Up; SW_PUSH_6mm
SW8: Page Previous; SW_PUSH_6mm
SW9: F1; SW_PUSH_6mm
SW10: F7; SW_PUSH_6mm
SW11: Edit_Compare; SW_PUSH_6mm
SW12: 2; SW_PUSH_6mm
SW13: Down; SW_PUSH_6mm
SW14: 8; SW_PUSH_6mm
SW15: Page Next; SW_PUSH_6mm
SW16: F2; SW_PUSH_6mm
SW17: F8; SW_PUSH_6mm
SW18: Copy; SW_PUSH_6mm
SW19: 3; SW_PUSH_6mm
SW20: 9; SW_PUSH_6mm
SW21: Bank / Select; SW_PUSH_6mm
SW22: Left; SW_PUSH_6mm
SW23: F3; SW_PUSH_6mm
SW24: Exit; SW_PUSH_6mm
SW25: Memory; SW_PUSH_6mm
SW26: 0; SW_PUSH_6mm
SW27: 4; SW_PUSH_6mm
SW28: Element; SW_PUSH_6mm
SW29: F4; SW_PUSH_6mm
SW30: Right; SW_PUSH_6mm
SW31: EF Bypass; SW_PUSH_6mm
SW32: Sign; SW_PUSH_6mm
SW33: F5; SW_PUSH_6mm
SW34: 5; SW_PUSH_6mm
SW35: -1/No; SW_PUSH_6mm
SW36: Operator; SW_PUSH_6mm
SW37: 6; SW_PUSH_6mm
SW38: Enter; SW_PUSH_6mm
SW39: +1/Yes; SW_PUSH_6mm
SW40: Knob 1; PEC164015FN0024; Mouser Part Number 652-PEC16-4015FN0024
SW41: Knob 5; PEC164015FN0024; Mouser Part Number 652-PEC16-4015FN0024
SW42: Data Entry Rotary; RotaryEncoder_Alps_EC11E-Switch_Vertical_H20mm
SW43: Knob 2; PEC164015FN0024; Mouser Part Number 652-PEC16-4015FN0024
SW44: Knob 6; PEC164015FN0024; Mouser Part Number 652-PEC16-4015FN0024
SW45: Knob 3; PEC164015FN0024; Mouser Part Number 652-PEC16-4015FN0024
SW46: Volume; PEC164015FN0024; Mouser Part Number 652-PEC16-4015FN0024
SW47: Knob 4; PEC164015FN0024; Mouser Part Number 652-PEC16-4015FN0024
SW48: Jump; SW_PUSH_6mm
SW49: Voice; SW_PUSH_6mm
SW50: Multi; SW_PUSH_6mm
U1: ATMEGA2560-16AU; TQFP-100_14x14mm; MPN ATMEGA2560-16AU; Digi-Key_PN ATMEGA2560-16AU-ND
U2: MCP23017_SO (0x20); SOIC-28W_7.5x17.9mm_P1.27mm
U3: MCP23017_SO (0x21); SOIC-28W_7.5x17.9mm_P1.27mm
U4: MCP23017_SO (0x22); SOIC-28W_7.5x17.9mm_P1.27mm
U5: CY7C65213-28PVXI; SSOP-28_5.3x10.2mm_P0.65mm
U6: MCP23017_SO (0x24); SOIC-28W_7.5x17.9mm_P1.27mm
Y1: Crystal 16MHz; Crystal_SMD_3225-4Pin_3.2x2.5mm_HandSoldering

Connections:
+3V3: J1.19
+5V: C3.2, C4.2, C5.1, C6.2, C7.1, IC1.8 (VCC), J1.18, J2.2 (VCC), J3.3, J3.6, J5.5, R1.1, R2.1, R3.2, R4.1, R5.2, R6.1, R7.2, R12.2, R13.1, R14.2, RV2.1, RV3.3, U1.10 (VCC), U1.31 (VCC), U1.61 (VCC), U1.80 (VCC), U1.100 (AVCC), U2.9 (VDD), U3.9 (VDD), U3.15 (A0), U4.9 (VDD), U4.16 (A1), U5.4 (VCCIO), U6.9 (VDD), U6.17 (A2)
/A0: RV3.2, U1.97 (PF0(ADC0))
/A1: U1.96 (PF1(ADC1))
/A2: U1.95 (PF2(ADC2))
/A3: U1.94 (PF3(ADC3))
/A4: U1.93 (PF4(ADC4/TCK))
/A5: U1.92 (PF5(ADC5/TMS))
/A6: U1.91 (PF6(ADC6/TDO))
/A7: U1.90 (PF7(ADC7/TDI))
/A8: U1.89 (PK0(ADC8/PCINT16))
/A9: U1.88 (PK1(ADC9/PCINT17))
/A10: U1.87 (PK2(ADC10/PCINT18))
/A11: U1.86 (PK3(ADC11/PCINT19))
/A12: U1.85 (PK4(ADC12/PCINT20))
/A13: U1.84 (PK5(ADC13/PCINT21))
/A14: U1.83 (PK6(ADC14/PCINT22))
/A15: U1.82 (PK7(ADC15/PCINT23))
/AREF: U1.98 (AREF)
/AVR_RX: U1.3 (PE1(TXD0)), U5.5 (RXD)
/AVR_TX: U1.2 (PE0(RXD0/PCINT8)), U5.1 (TXD)
/CD: J3.8, U1.63 (PJ0(RXD3/PCINT9))
/D2: U1.6 (PE4(OC3B/INT4))
/D3: U1.7 (PE5(OC3C/INT5))
/D4: J3.15, U1.1 (PG5(OC08))
/D5: J3.16, U1.5 (PE3(OC3A/AIN1))
/D6: J3.17, U1.15 (PH3(OC4A))
/D7: J3.18, U1.16 (PH4(OC4B))
/D8: J3.11, U1.17 (PH5(OC4C))
/D9: J3.12, U1.18 (PH6(OC2B))
/D10: J3.13, U1.23 (PB4(OC2A/PCINT4))
/D11: J3.14, U1.24 (PB5(OC1A/PCINT5))
/D12: U1.25 (PB6(OC1B/PCINT6))
/D13: U1.26 (PB7(OC0A/OC1C/PCINT7))
/D22: J5.1, U1.78 (PA0(AD0))
/D23: U1.77 (PA1(AD1))
/D24: U1.76 (PA2(AD2))
/D25: SW42.B, U1.75 (PA3(AD3))
/D26: SW42.A, U1.74 (PA4(AD4))
/D27: SW44.C1 (CW), U1.73 (PA5(AD5))
/D28: SW44.A1 (CCW), U1.72 (PA6(AD6))
/D29: SW41.C1 (CW), U1.71 (PA7(AD7))
/D30: SW47.C1 (CW), U1.60 (PC7(A15))
/D31: SW47.A1 (CCW), U1.59 (PC6(A14))
/D32: SW45.C1 (CW), U1.58 (PC5(A13))
/D33: SW45.A1 (CCW), U1.57 (PC4(A12))
/D34: SW43.C1 (CW), U1.56 (PC3(A11))
/D35: SW43.A1 (CCW), U1.55 (PC2(A10))
/D36: SW40.C1 (CW), U1.54 (PC1(A9))
/D37: SW40.A1 (CCW), U1.53 (PC0(A8))
/D38: U1.50 (PD7(T0))
/D39: SW41.A1 (CCW), U1.70 (PG2(ALE))
/D40: SW46.C1 (CW), U1.52 (PG1(~RD~))
/D41: SW46.A1 (CCW), U1.51 (PG0(~WR~))
/D42: U1.42 (PL7)
/D43: U1.41 (PL6)
/D44: U1.40 (PL5(OC5C))
/D45: U1.39 (PL4(OC5B))
/D46: U1.38 (PL3(OC5A))
/D47: U1.37 (PL2(T5))
/D48: U1.36 (PL1(ICP5))
/D49: U1.35 (PL0(ICP4))
/D+: J4.A6 (DP1), J4.B6 (DP2), U5.15 (USBDP)
/D-: J4.A7 (DN1), J4.B7 (DN2), U5.16 (USBDM)
/DPad_Down: SW13.1, U3.5 (GPB4)
/DPad_Element: SW28.1, U3.8 (GPB7)
/DPad_Jump: SW48.1, U3.26 (GPA5)
/DPad_Left: SW22.1, U3.1 (GPB0)
/DPad_No: SW35.1, U3.2 (GPB1)
/DPad_Operator: SW36.1, U3.25 (GPA4)
/DPad_Page_Next: SW15.1, U3.7 (GPB6)
/DPad_Page_Prev: SW8.1, U3.3 (GPB2)
/DPad_Right: SW30.1, U3.28 (GPA7)
/DPad_Select: SW21.1, U3.4 (GPB3)
/DPad_Up: SW7.1, U3.6 (GPB5)
/DPad_Yes: SW39.1, U3.27 (GPA6)
/FK_Exit: SW24.1, U6.22 (GPA1)
/FK_F1: SW9.1, U6.2 (GPB1)
/FK_F2: SW16.1, U6.3 (GPB2)
/FK_F3: SW23.1, U6.4 (GPB3)
/FK_F4: SW29.1, U6.5 (GPB4)
/FK_F5: SW33.1, U6.6 (GPB5)
/FK_F6: SW3.1, U6.7 (GPB6)
/FK_F7: SW10.1, U6.8 (GPB7)
/FK_F8: SW17.1, U6.21 (GPA0)
/FK_Shift: SW2.1, U6.1 (GPB0)
/I2S_MUTE: J1.12
/I2S_SCK: J1.15
/I2S_SDA: J1.13
/I2S_WS: J1.14
/LED_A: J3.21, RV2.2, RV2.3
/MD_Copy: SW18.1, U4.28 (GPA7)
/MD_EF_Bypass: SW31.1, U4.1 (GPB0)
/MD_Edit: SW11.1, U4.2 (GPB1)
/MD_Memory: SW25.1, U4.26 (GPA5)
/MD_Multi: SW50.1, U4.27 (GPA6)
/MD_Utility: SW4.1, U4.25 (GPA4)
/MD_Voice: SW49.1, U4.3 (GPB2)
/MIDI_IN: J1.3
/MIDI_IN_INV: J1.4
/MIDI_OUT: J1.5
/MIDI_OUT_INV: J1.6
/MISO_D50: J2.1 (MISO), J5.4, U1.22 (PB3(MISO/PCINT3))
/MOSI_D51: J2.4 (MOSI), J5.3, U1.21 (PB2(MOSI/PCINT2))
/NC: J3.9
/Numpad_0: SW26.1, U2.1 (GPB0)
/Numpad_1: SW5.1, U2.2 (GPB1)
/Numpad_2: SW12.1, U2.6 (GPB5)
/Numpad_3: SW19.1, U2.27 (GPA6)
/Numpad_4: SW27.1, U2.3 (GPB2)
/Numpad_5: SW34.1, U2.7 (GPB6)
/Numpad_6: SW37.1, U2.26 (GPA5)
/Numpad_7: SW6.1, U2.4 (GPB3)
/Numpad_8: SW14.1, U2.8 (GPB7)
/Numpad_9: SW20.1, U2.25 (GPA4)
/Numpad_Enter: SW38.1, U2.28 (GPA7)
/Numpad_Sign: SW32.1, U2.5 (GPB4)
/RESET: J2.5 (~RST), R1.2, SW1.1, U1.30 (~RESET)
/RX1_D45: J1.7, U1.45 (PD2(RXD1/INT2))
/RX2_D17: J3.5, U1.12 (PH0(RXD2))
/SCK_D52: J2.3 (SCK), J5.2, U1.20 (PB1(SCK/PCINT1))
/SCL_D21: IC1.6 (SCL), R3.1, R5.1, R7.1, R14.1, U1.43 (PD0(SCL/INT0)), U2.12 (SCK), U3.12 (SCK), U4.12 (SCK), U6.12 (SCK)
/SDA_D20: IC1.5 (SDA), R2.2, R4.2, R6.2, R13.2, U1.44 (PD1(SDA/INT1)), U2.13 (SDA), U3.13 (SDA), U4.13 (SDA), U6.13 (SDA)
/SPDIF_OUT: J1.11
/SS_D53: U1.19 (PB0(~SS~/PCINT0))
/TX1_D46: J1.8, U1.46 (PD3(TXD1/INT3))
/TX2_D16: J3.10, U1.13 (PH1(TXD2))
/TX3_D14: J3.7, U1.64 (PJ1(TXD3/PCINT10))
/UART_RX_3.3V: J1.2
/UART_TX_3.3V: J1.1
/V0: J3.4, RV1.2
/VBUS: C8.1, C9.2, J4.A4_B9 (VBUS), J4.B4_A9 (VBUS), R8.1, U5.20 (VCC)
/VOUT: J3.20, RV1.1
GND: C1.2, C2.2, C3.1, C4.1, C5.2, C6.1, C7.2, C8.2, C9.1, C10.1, D1.1 (K), IC1.1 (A0), IC1.2 (A1), IC1.3 (A2), IC1.4 (GND), IC1.7 (WP), J1.20, J2.6 (GND), J3.1, J3.2, J3.19, J3.22, J4.A1_B12 (GND), J4.B1_A12 (GND), J5.6, R9.2, R10.2, R11.2, RV1.3, RV3.1, SW1.2, SW2.2, SW3.2, SW4.2, SW5.2, SW6.2, SW7.2, SW8.2, SW9.2, SW10.2, SW11.2, SW12.2, SW13.2, SW14.2, SW15.2, SW16.2, SW17.2, SW18.2, SW19.2, SW20.2, SW21.2, SW22.2, SW23.2, SW24.2, SW25.2, SW26.2, SW27.2, SW28.2, SW29.2, SW30.2, SW31.2, SW32.2, SW33.2, SW34.2, SW35.2, SW36.2, SW37.2, SW38.2, SW39.2, SW40.B1 (WIPER), SW41.B1 (WIPER), SW42.C, SW43.B1 (WIPER), SW44.B1 (WIPER), SW45.B1 (WIPER), SW46.B1 (WIPER), SW47.B1 (WIPER), SW48.2, SW49.2, SW50.2, U1.11 (GND), U1.32 (GND), U1.62 (GND), U1.81 (GND), U1.99 (GND), U2.10 (VSS), U2.15 (A0), U2.16 (A1), U2.17 (A2), U2.18 (~RESET~), U3.10 (VSS), U3.16 (A1), U3.17 (A2), U3.18 (~RESET~), U4.10 (VSS), U4.15 (A0), U4.17 (A2), U4.18 (~RESET~), U5.7 (GND), U5.18 (GND), U5.21 (GND), U6.10 (VSS), U6.15 (A0), U6.16 (A1), U6.18 (~RESET~)
unnamed: C1.1, U1.33 (XTAL2), Y1.1
unnamed: C2.1, U1.34 (XTAL1), Y1.2
unnamed: C10.2, U5.17 (VCCD)
unnamed: D1.2 (A), R12.1
unnamed: J4.A5 (CC1), R10.1
unnamed: J4.B5 (CC2), R11.1
unnamed: R8.2, R9.1, U5.19 (~RESET)

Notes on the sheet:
External Connections
XVA/XFM2 Extended Board Connector
AVR ISP Programmer
Microcontroller
ATMEGA2560
Reset Switch
Display
Bypass Caps
User Interace: Data Entry Rotary Knobs
ATMEGA2560 Power
Power
USB-UART
EEPROM
LEDs
User Interace: Mode Keys
User Interace: Function Keys
User Interace: Data Pad
User Interace: Numpad

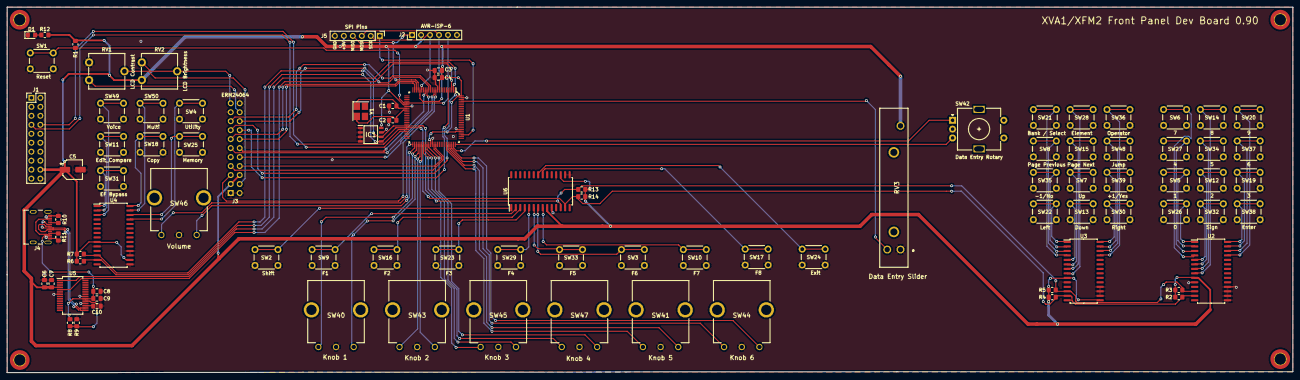
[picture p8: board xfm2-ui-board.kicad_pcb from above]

Board: 2 copper layers, 363.7 x 103.4 mm, 91 parts (1 on the bottom side), 96 nets.

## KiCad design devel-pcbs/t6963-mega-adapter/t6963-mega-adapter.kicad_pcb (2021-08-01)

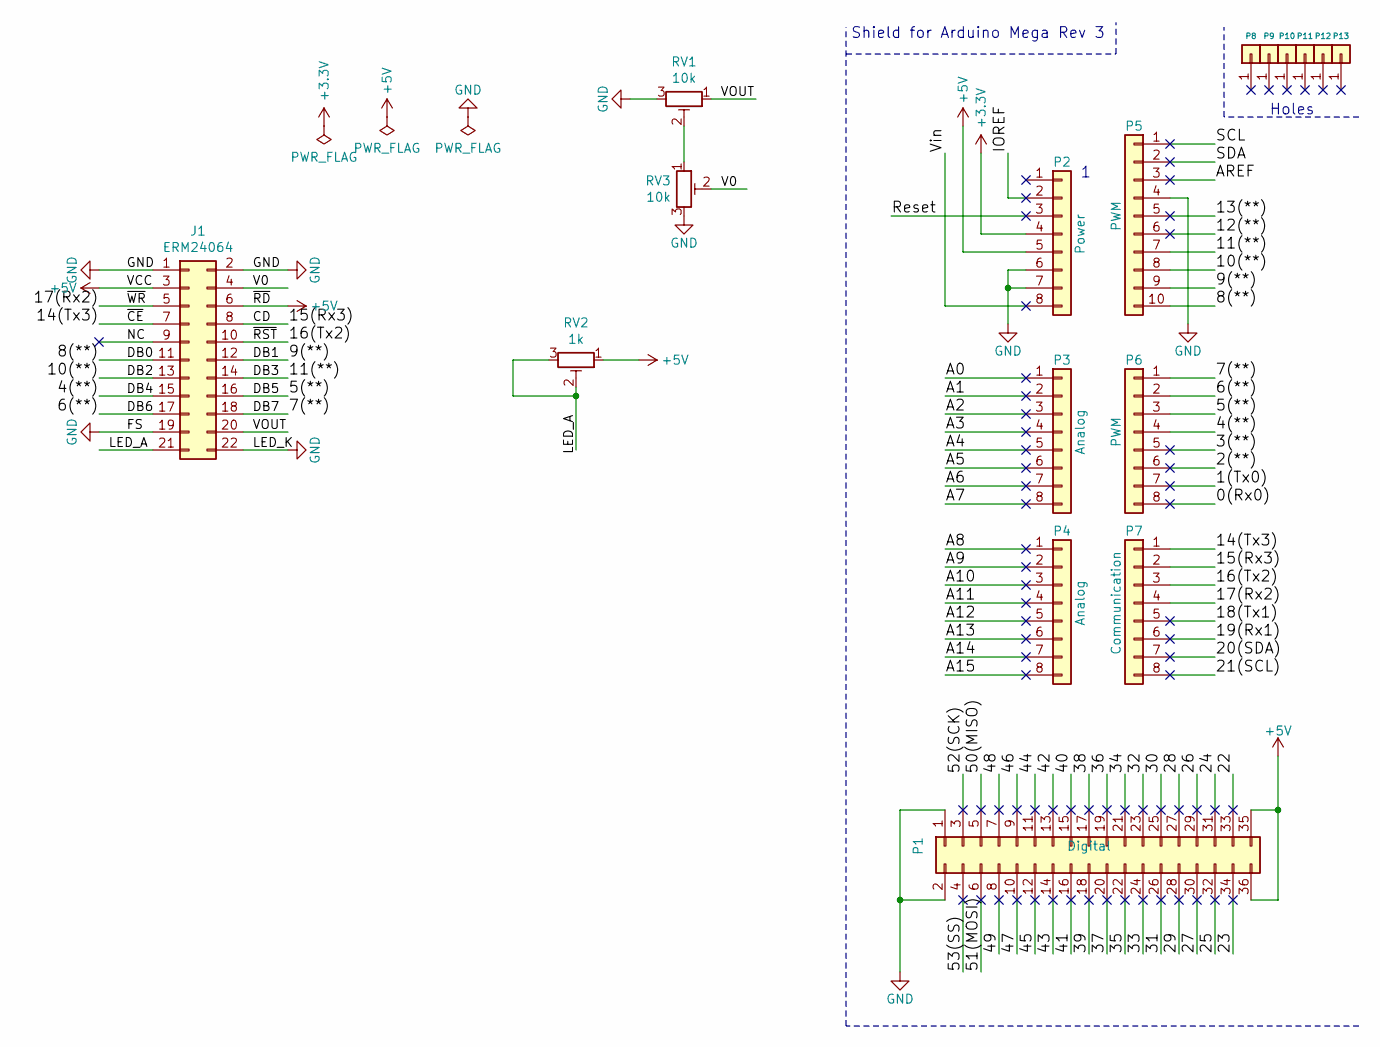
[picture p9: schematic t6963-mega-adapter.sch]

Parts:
J1: ERM24064; PinHeader_2x11_P2.54mm_Vertical
P1: Digital; Socket_Strip_Arduino_2x18
P2: Power; Socket_Strip_Arduino_1x08
P3, P4: Analog; Socket_Strip_Arduino_1x08
P5: PWM; Socket_Strip_Arduino_1x10
P6: PWM; Socket_Strip_Arduino_1x08
P7: Communication; Socket_Strip_Arduino_1x08
P8, P9, P10, P11, P12, P13: CONN_01X01; Arduino_1pin
RV1, RV3: 10k; Potentiometer_ACP_CA9-V10_Vertical
RV2: 1k; Potentiometer_ACP_CA9-V10_Vertical

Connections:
+3V3: P2.4
+5V: J1.3, J1.6, P1.35, P1.36, P2.5, RV2.1
/0(Rx0): P6.8
/1(Tx0): P6.7
/2(**): P6.6
/3(**): P6.5
/4(**): J1.15, P6.4
/5(**): J1.16, P6.3
/6(**): J1.17, P6.2
/7(**): J1.18, P6.1
/8(**): J1.11, P5.10
/9(**): J1.12, P5.9
/10(**): J1.13, P5.8
/11(**): J1.14, P5.7
/12(**): P5.6
/13(**): P5.5
/14(Tx3): J1.7, P7.1
/15(Rx3): J1.8, P7.2
/16(Tx2): J1.10, P7.3
/17(Rx2): J1.5, P7.4
/18(Tx1): P7.5
/19(Rx1): P7.6
/20(SDA): P7.7
/21(SCL): P7.8
/22: P1.33
/23: P1.34
/24: P1.31
/25: P1.32
/26: P1.29
/27: P1.30
/28: P1.27
/29: P1.28
/30: P1.25
/31: P1.26
/32: P1.23
/33: P1.24
/34: P1.21
/35: P1.22
/36: P1.19
/37: P1.20
/38: P1.17
/39: P1.18
/40: P1.15
/41: P1.16
/42: P1.13
/43: P1.14
/44: P1.11
/45: P1.12
/46: P1.9
/47: P1.10
/48: P1.7
/49: P1.8
/50(MISO): P1.5
/51(MOSI): P1.6
/52(SCK): P1.3
/53(SS): P1.4
/A0: P3.1
/A1: P3.2
/A2: P3.3
/A3: P3.4
/A4: P3.5
/A5: P3.6
/A6: P3.7
/A7: P3.8
/A8: P4.1
/A9: P4.2
/A10: P4.3
/A11: P4.4
/A12: P4.5
/A13: P4.6
/A14: P4.7
/A15: P4.8
/AREF: P5.3
/IOREF: P2.2
/LED_A: J1.21, RV2.2, RV2.3
/NC: J1.9
/Reset: P2.3
/SCL: P5.1
/SDA: P5.2
/V0: J1.4, RV3.2
/VOUT: J1.20, RV1.1
/Vin: P2.8
GND: J1.1, J1.2, J1.19, J1.22, P1.1, P1.2, P2.6, P2.7, P5.4, RV1.3, RV3.3
unnamed: RV1.2, RV3.1

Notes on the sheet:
Shield for Arduino Mega Rev 3
Holes

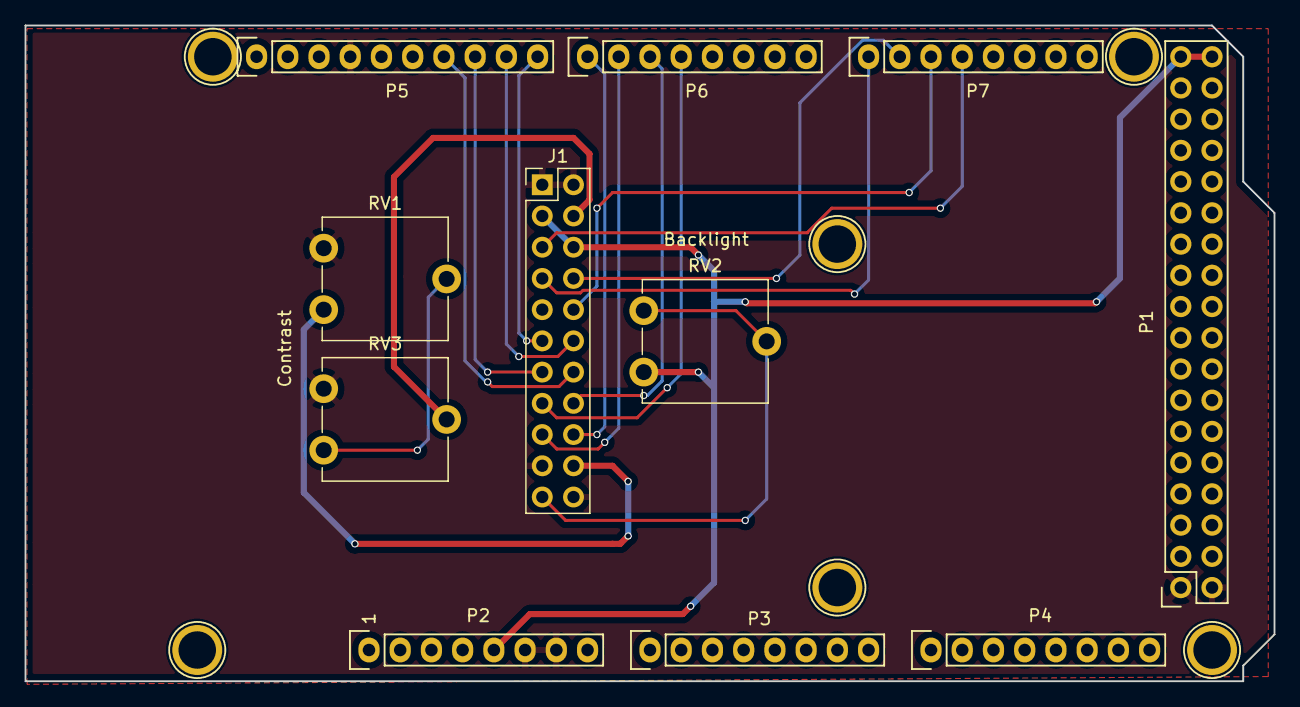
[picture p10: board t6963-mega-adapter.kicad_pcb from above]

Board: 2 copper layers, 101.6 x 53.3 mm, 17 parts (0 on the bottom side), 18 nets.

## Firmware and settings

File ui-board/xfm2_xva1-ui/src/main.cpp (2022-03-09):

#include <Arduino.h>
#include "ctrlboard/ctrlboard.h"
#include "common.h"

CtrlBoard *ctrlboard;

// ---------------------------------------------------------------------------------------

void setup() {
  VoiceModel *voiceModel;

  Serial.begin(500000); // for monitoring

  setupUi();
  auto *voiceMode = new VoiceMode(nullptr);
  //voiceModel = new VoiceModel(patchNames[0]);  // adapt the index zero later
  voiceModel = new VoiceModel(patchNames[0], 0);  // adapt the index zero later
  voiceMode->updateVoiceModel(voiceModel);
  ctrlboard = new CtrlBoard();
  ctrlboard->setVoiceMode(voiceMode);

}

// =======================================================================================
// Loop
// =======================================================================================

void loop(void) {
  ctrlboard->handleLoop();
//  printFreeMemory();
//  testScreen();
//  delay(10000);
}

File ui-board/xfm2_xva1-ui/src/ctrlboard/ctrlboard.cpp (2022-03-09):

#include "ctrlboard.h"
#include "../common.h"
#include <Arduino.h>

// ---------------------------------------------------------------------------------------

CtrlBoard::CtrlBoard() {
  mcp_functionkeys.begin_I2C(MCP_FUNCTION_KEYS_ADDRESS);
  mcp_datapad.begin_I2C(MCP_DATAPAD_ADDRESS);
  mcp_modekeys.begin_I2C(MCP_MODE_KEYS_ADDRESS);
  mcp_numpad.begin_I2C(MCP_NUMPAD_ADDRESS);
  initializeFunctionButtons();
  initializeDatapadButtons();
  initializeNumpadButtons();
  initializeModeButtons();
  this->xfm2Hw = new Xfm2Hw(&Serial1);
  this->xfm2Unit1 = new Xfm2Program(this->xfm2Hw);
  this->xfm2Unit2 = new Xfm2Program(this->xfm2Hw);
  this->xfm2Hw->loadProgram(0);
}

// ---------------------------------------------------------------------------------------

CtrlBoard::~CtrlBoard() = default;

// ---------------------------------------------------------------------------------------

void CtrlBoard::initializeFunctionButtons() {
  mcp_functionkeys.pinMode(BUTTON_FK_SHIFT, INPUT_PULLUP);
  mcp_functionkeys.pinMode(BUTTON_FK_F1, INPUT_PULLUP);
  mcp_functionkeys.pinMode(BUTTON_FK_F2, INPUT_PULLUP);
  mcp_functionkeys.pinMode(BUTTON_FK_F3, INPUT_PULLUP);
  mcp_functionkeys.pinMode(BUTTON_FK_F4, INPUT_PULLUP);
  mcp_functionkeys.pinMode(BUTTON_FK_F5, INPUT_PULLUP);
  mcp_functionkeys.pinMode(BUTTON_FK_F6, INPUT_PULLUP);
  mcp_functionkeys.pinMode(BUTTON_FK_F7, INPUT_PULLUP);
  mcp_functionkeys.pinMode(BUTTON_FK_F8, INPUT_PULLUP);
  mcp_functionkeys.pinMode(BUTTON_FK_EXIT, INPUT_PULLUP);
}

// ---------------------------------------------------------------------------------------

void CtrlBoard::initializeDatapadButtons() {
  mcp_datapad.pinMode(BUTTON_DPAD_UP, INPUT_PULLUP);
  mcp_datapad.pinMode(BUTTON_DPAD_DOWN, INPUT_PULLUP);
  mcp_datapad.pinMode(BUTTON_DPAD_LEFT, INPUT_PULLUP);
  mcp_datapad.pinMode(BUTTON_DPAD_RIGHT, INPUT_PULLUP);
  mcp_datapad.pinMode(BUTTON_DPAD_ELEMENT, INPUT_PULLUP);
  mcp_datapad.pinMode(BUTTON_DPAD_JUMP, INPUT_PULLUP);
  mcp_datapad.pinMode(BUTTON_DPAD_NO, INPUT_PULLUP);
  mcp_datapad.pinMode(BUTTON_DPAD_OPERATOR, INPUT_PULLUP);
  mcp_datapad.pinMode(BUTTON_DPAD_PAGE_NEXT, INPUT_PULLUP);
  mcp_datapad.pinMode(BUTTON_DPAD_PAGE_PREV, INPUT_PULLUP);
  mcp_datapad.pinMode(BUTTON_DPAD_SELECT, INPUT_PULLUP);
  mcp_datapad.pinMode(BUTTON_DPAD_YES, INPUT_PULLUP);
}

// ---------------------------------------------------------------------------------------

void CtrlBoard::initializeNumpadButtons() {
  mcp_numpad.pinMode(BUTTON_NUMPAD_0, INPUT_PULLUP);
  mcp_numpad.pinMode(BUTTON_NUMPAD_1, INPUT_PULLUP);
  mcp_numpad.pinMode(BUTTON_NUMPAD_2, INPUT_PULLUP);
  mcp_numpad.pinMode(BUTTON_NUMPAD_3, INPUT_PULLUP);
  mcp_numpad.pinMode(BUTTON_NUMPAD_4, INPUT_PULLUP);
  mcp_numpad.pinMode(BUTTON_NUMPAD_5, INPUT_PULLUP);
  mcp_numpad.pinMode(BUTTON_NUMPAD_6, INPUT_PULLUP);
  mcp_numpad.pinMode(BUTTON_NUMPAD_7, INPUT_PULLUP);
  mcp_numpad.pinMode(BUTTON_NUMPAD_8, INPUT_PULLUP);
  mcp_numpad.pinMode(BUTTON_NUMPAD_9, INPUT_PULLUP);
  mcp_numpad.pinMode(BUTTON_NUMPAD_ENTER, INPUT_PULLUP);
  mcp_numpad.pinMode(BUTTON_NUMPAD_SIGN, INPUT_PULLUP);
}

// ---------------------------------------------------------------------------------------

void CtrlBoard::initializeModeButtons() {
  mcp_modekeys.pinMode(BUTTON_MD_UTILITY, INPUT_PULLUP);
  mcp_modekeys.pinMode(BUTTON_MD_COPY, INPUT_PULLUP);
  mcp_modekeys.pinMode(BUTTON_MD_EDIT, INPUT_PULLUP);
  mcp_modekeys.pinMode(BUTTON_MD_EF_BYPASS, INPUT_PULLUP);
  mcp_modekeys.pinMode(BUTTON_MD_MEMORY, INPUT_PULLUP);
  mcp_modekeys.pinMode(BUTTON_MD_MULTI, INPUT_PULLUP);
  mcp_modekeys.pinMode(BUTTON_MD_VOICE, INPUT_PULLUP);
}

// ---------------------------------------------------------------------------------------

void CtrlBoard::setVoiceMode(VoiceMode *voiceModeParam) {
  this->voiceMode = voiceModeParam;
  updateVoiceModel();
}

// ---------------------------------------------------------------------------------------

void CtrlBoard::handleLoop() {
// processing ui
//  if (Serial.available()) {
//    char val = Serial.read(); // NOLINT(cppcoreguidelines-narrowing-conversions)
//
//    switch (val) {
//    case 'u': // up
//    case 'd': // down
//    case 'e': // enter
//      break;
//    case 'l': // left
//      voiceNumber--;
//      if (voiceNumber < 0)
//        voiceNumber = 4;
//      updateVoiceModel();
//      break;
//    case 'r': // right
//      voiceNumber++;
//      if (voiceNumber > 4)
//        voiceNumber = 0;
//      updateVoiceModel();
//      break;
//    default:break;
//    }
//  }
  handleFunctionButtons();
  handleDatapadButtons();
  handleNumpadButtons();
  handleModeButtons();
}

// ---------------------------------------------------------------------------------------
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

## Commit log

2021-04-30 add gerber zip.
2021-05-14 Initial version of the extended board. Untested.
    [xfm2-odd_routing.kicad_pcb, xfm2.kicad_pcb, xfm2.sch]
2021-05-14 fix for 3d view.
    [xfm2.kicad_pcb]
2021-05-14 Teaser for the extended board.
2021-06-11 removed unnecessary file.
    [xfm2-odd_routing.kicad_pcb]
2021-06-17 updated schematic
    [xfm2.kicad_pcb, xfm2.sch]
2021-06-21 nicer schematic, control voltage, power supply, power cleanups
    [xfm2.sch]
2021-06-21 initial extended pcb 1.1 placement
    [xfm2.kicad_pcb, xfm2.sch]
2021-06-26 power updates.
    [xfm2.kicad_pcb, xfm2.sch]
2021-06-26 first routes.
    [xfm2.kicad_pcb, xfm2.sch]
2021-06-27 fitted the 6.35mm audio jack which was too small. Added gerbers. ERC seems fine.
    [xfm2-B_Cu.gbr, xfm2-B_Mask.gbr, xfm2-B_Paste.gbr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]
2021-07-18 fix for memory leaks
    [main.cpp]
2021-08-01 development pcb to connect the display to avoid unnecessary cabling.
    [t6963-mega-adapter-B_Adhes.gbr, t6963-mega-adapter-B_CrtYd.gbr, t6963-mega-adapter-B_Cu.gbr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]
2021-08-01 prototype for mcp23017 multiplexed buttons
2021-08-02 removed softwareserial, moved hacky stuff to ctrlboard class. switching voices up and down kinda works, but is still very hacky.
2021-08-07 fixes for the serial code
    [xfm2.cpp]
2021-08-07 cleanups, pitch eg implementation
2021-09-12 updates for the extended xfm2 board: replacement of opamp components, logic level converter 5v<->3.3v and pull ups for uart.
    [xfm2.kicad_pcb, xfm2.sch]
2021-09-19 xfm2/xva pcb version 1.3 (untested, don't use yet).
    [xfm2-B_Cu.gbr, xfm2-B_Mask.gbr, xfm2-B_Paste.gbr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]
2021-09-20 v1.31 pcb. fix for a weird oval hole in the used usb-c connector footprint.
    [xfm2-B_Cu.gbr, xfm2-B_Mask.gbr, xfm2-B_Paste.gbr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]
2021-10-02 Next bugfix version 1.33.
    [xfm2-B_Cu.gbr, xfm2-B_Mask.gbr, xfm2-B_Paste.gbr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]
2021-10-02 missed a file...
    [xfm2.sch]
2021-10-23 bugfix incl. gerber v1.34 for the extended board.
    [xfm2-B_Cu.gbr, xfm2-B_Mask.gbr, xfm2-B_Paste.gbr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]
2021-10-23 fix schema date for v1.34
    [xfm2.sch]
2021-10-24 unwired ui develeopment board is mostly done.
    [xfm2-ui-board.kicad_pcb, xfm2-ui-board.sch]
2021-10-25 lots of ui board routing
    [xfm2-ui-board.kicad_pcb, xfm2-ui-board.sch]
2021-10-28 fully routed.
    [xfm2-ui-board.kicad_pcb]
2021-10-28 small corrections + mounting holes.
    [xfm2-ui-board.kicad_pcb]
2021-10-29 small changes + gerber for front panel dev board
    [xfm2-ui-board-B_Cu.gbr, xfm2-ui-board-B_Mask.gbr, xfm2-ui-board-B_Paste.gbr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]
2021-10-29 updated footprint for the crystal
    [xfm2-ui-board-B_Cu.gbr, xfm2-ui-board-B_Mask.gbr, xfm2-ui-board-B_Paste.gbr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]
2022-03-06 version 1.40 with kicad 6 migration
    [xfm2-B_Cu.gbr, xfm2-B_Mask.gbr, xfm2-B_Paste.gbr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]
2022-03-06 v1.40 including jlcpcb assembly files.
    [xfm2_xva1_extended_board_v1.40-top-bom.csv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]
2022-03-06 updated gerber
    [xfm2-B_Cu.gbr, xfm2-B_Mask.gbr, xfm2-B_Paste.gbr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]
2022-03-07 removed mcp6004 from assembly file (so-14 footprint slightly too big).
    [xfm2_xva1_extended_board_v1.40-top-bom.csv]
2022-03-09 example buttons for each multiplexer.
2022-03-29 assembly files corrections.
    [xfm2_xva1_extended_board_v1.40-top-pos.csv]
2022-04-17 pdf schematic + layout.
